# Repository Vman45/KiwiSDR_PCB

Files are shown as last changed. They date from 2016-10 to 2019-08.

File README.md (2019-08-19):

[updated 28 May 2018]

KiwiSDR (http://www.kiwisdr.com/ks/Seeed.sample.1.jpg)

Click image for full size.

[KiwiSDR© bluebison.net](http://bluebison.net)

KiwiSDR
=======

Software-defined Radio (SDR) and GPS for the BeagleBone Black
----------------------------------------------------------------------

An add-on board ("cape") that turns your Beagle into a web-accessible shortwave receiver.

This repository contains the KiCAD files (schematics, board layout), Gerbers, BOM and other files used to produce the KiwiSDR PCB.
Also included here is the design for an active antenna and bias tee.

**Note: the active antenna and bias tee schematics and PCBs here are still undergoing development and do not work properly. Do not fabricate the PCBs and expect them to work.**

The KiwiSDR software is located in the repository [Beagle_SDR_GPS](https://github.com/jks-prv/Beagle_SDR_GPS/).

### Kickstarter
KiwiSDR had a successful [Kickstarter](https://www.kickstarter.com/projects/1575992013/kiwisdr-beaglebone-software-defined-radio-sdr-with/).

### Details

* Listen live: [SDR.hu](https://sdr.hu/?top=kiwi), [kiwisdr.com](http://kiwisdr.com/public), [rx.linkfanel.net](http://rx.linkfanel.net)
* [Project webpage](http://www.kiwisdr.com/)
* [Operating information: installation, operation, FAQ](http://www.kiwisdr.com/quickstart/)
* Latest [source code commits](https://github.com/jks-prv/Beagle_SDR_GPS/commits/master)
* [Design review document](https://www.dropbox.com/s/i1bjyp1acghnc16/KiwiSDR.design.review.pdf?dl=1)
* [Schematic](http://www.kiwisdr.com/docs/KiwiSDR/kiwi.schematic.pdf), [Gerbers](http://www.kiwisdr.com/docs/KiwiSDR/kiwi.gerbers.tar), [Active antenna](http://www.kiwisdr.com/docs/KiwiSDR/ant.pdf), [BOM ODS](http://www.kiwisdr.com/docs/KiwiSDR/kiwi.bom.ods), [BOM XLS](http://www.kiwisdr.com/docs/KiwiSDR/kiwi.bom.xls)

### Description
This SDR is a bit different. It has a web interface that can be used by up to four separate listeners. Each one listening and tuning an independent frequency simultaneously. See the screenshots below.

### Components
* SDR covering the 10 kHz to 30 MHz (VLF-HF) spectrum.
* Web interface based on [OpenWebRX](http://openwebrx.org/) from András Retzler, HA7ILM.
* Integrated software-defined GPS receiver from Andrew Holme's [Homemade GPS Receiver](http://www.aholme.co.uk/GPS/Main.htm).
* LTC 14-bit 65 MHz ADC.
* Xilinx Artix-7 A35 FPGA.
* Skyworks SE4150L GPS front-end.

### Features
* 100% Open Source / Open Hardware.
* Browser-based interface allowing multiple simultaneous user web connections (currently 4).
* Each connection tunes an independent receiver channel over the entire spectrum.
* Waterfall tunes independently of audio and includes zooming and panning.
* Multi-channel, parallel DDC design using bit-width optimized CIC filters.
* Good performance at VLF/LF since we personally spend time monitoring those frequencies.
* Automatic frequency calibration via received GPS timing.
* Easy hardware and software setup. Browser-based configuration interface.

### Status

Give the live receivers a try at the links above. You'll need a recent version of a modern web browser that supports HTML5. The web interface works, with some problems, on mobile devices. But there is no mobile version of the interface yet.

The files of a KiCAD PCB layout of the cape are available. This PCB has been fabricated in production quantities
and shipped to thousands of customers worldwide.
Please email us any comments you have after reviewing the design document above. The active antenna and injector PCBs have been fabricated and are undergoing development.

### Objectives

We wanted to design an SDR that provides certain features, at a low price point, that we felt weren't covered by current devices. The SDR must be web-accessible and simple to setup and use.
We also wanted to provide a self-contained platform for experimentation with SDR and GPS techniques. 

Most importantly, We'd really like to see a significant number of web-enabled, wide-band SDRs deployed in diverse locations world-wide because that makes possible some really interesting applications and experiments.

### Operation

Users can purchase just the KiwiSDR board or a complete "kit" consisting of the board, BeagleBone Green (software pre-installed), enclosure (assembly required), and GPS antenna (see [here](http://www.kiwisdr.com/)).
The software will try to automatically open up an incoming port through whatever Internet firewall/router may exist on the local network, but the user may have to perform this step manually. An antenna solution must be provided. An adequate power supply to the Beagle (e.g. 5V @ 2A) will also be required.

Four channels of audio and waterfall streamed over the Internet 24/7 requires about 30 GB per month. This is a common cap for many residential broadband plans. An automatic dynamic-DNS system is already part of the software so a web link to the SDR is immediately available with no configuration. Of course the system can be configured to only allow connections from the local network and ignore Internet connection requests.

### Web interface screenshots

Click images for full size.

View of entire 0-30 MHz range:

(http://www.kiwisdr.com/ks/ss.full.jpg)

Moderate zoom of medium-wave broadcast band with spectrum display on top enabled:

(http://www.kiwisdr.com/ks/ss.MW.jpg)

Over-the-horizon-radar (OTHR) from Cyprus showing short-term ionospheric fluctuations:

(http://www.kiwisdr.com/ks/ss.Cyprus.jpg)

VLF/LF reception in New Zealand

| kHz | Station | Location | Signal |
| :-- | :--- | :--- | :----- |
| 12.88 | Alpha | Khabarovsk & Novosibirsk Russia | Navigation system |
| 17.0 | VTX2 | India | MSK comms |
| 19.8 | NWC | Australia | MSK comms |
| 21.4 | NPM | Hawaii | MSK comms |
| 22.2 | NDT/JJI | Japan | MSK comms |
| 24.1 | (UNID) | Korea, per David L Wilson | FSK comms |
| 40.0 | JJY | Japan | Time signal |
| 45.9 | NSY | Italy | MSK comms |
| 54.0 | NDI | Japan | MSK comms |
| 60.0 | JJY/WWVB | Japan, USA | Time signals |
| 68.5 | BPC | China | Time signal |

Many others heard during different times and conditions.

(http://www.kiwisdr.com/ks/ss.VLF.LF.jpg)

[end-of-document]

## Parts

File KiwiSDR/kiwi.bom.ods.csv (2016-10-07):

item# | quan | value | mfg | P/N | package | place | refs | SMD marking | fine pitch | polarized | generic substitution | OPL | specs | critical spec | notes
#1 | 1 | 10n | Murata | GRM155R71C103KA01D | SM0402 | DNL | C107 |  |  |  | YES |  | 10% X7R 16V |  | DO NOT LOAD; ceramic capacitor
#2 | 2 | U.FL | Hirose | U.FL-R-SMT-1 | U.FL | DNL | J4 J5 |  |  |  | YES |  |  |  | DO NOT LOAD; coaxial connector
#3 | 1 | (no value) |  |  | SM0402 | DNL | R407 |  |  |  | YES |  |  |  | DO NOT LOAD
#4 | 1 | 0R | Panasonic | ERJ-2GE0R00X | SM0402 | SMT | R408 |  |  |  | YES |  |  |  | zero-ohm jumper
#5 | 1 | 10R | Panasonic | ERJ-2RKF10R0X | SM0402 | SMT | R701 |  |  |  | YES |  | 1% 100mW 50V |  | thick film resistor
#6 | 1 | 28R7 | Panasonic | ERJ-2RKF28R7X | SM0402 | SMT | R403 |  |  |  | YES |  | 1% 100mW 50V |  | thick film resistor
#7 | 1 | 66R5 | Panasonic | ERJ-2RKF66R5X | SM0402 | SMT | R402 |  |  |  | YES |  | 1% 100mW 50V |  | thick film resistor
#8 | 4 | 100R | Panasonic | ERJ-2RKF1000X | SM0402 | SMT | R101 R102 R103 R401 |  |  |  | YES |  | 1% 100mW 50V |  | thick film resistor
#9 | 1 | 1K5 | Panasonic | ERJ-2RKF1501X | SM0402 | SMT | R104 |  |  |  | YES |  | 1% 100mW 50V |  | thick film resistor
#10 | 3 | 5K6 | Panasonic | ERJ-2RKF5601X | SM0402 | SMT | R303 R304 R305 |  |  |  | YES |  | 1% 100mW 50V |  | thick film resistor
#11 | 1 | 6K65 | Panasonic | ERJ-2RKF6651X | SM0402 | SMT | R702 |  |  |  | YES |  | 1% 100mW 50V |  | thick film resistor
#12 | 4 | 10K | Panasonic | ERJ-2RKF1002X | SM0402 | SMT | R406 R409 R410 R703 |  |  |  | YES |  | 1% 100mW 50V |  | thick film resistor
#13 | 2 | 100R | Bourns | CAY16-101J8LF | RNET_CAY16_J8 | SMT | R404 R405 |  | FINE |  | YES |  | 5% 62.5mW 25V |  | isolated resistor array
#14 | 2 | 22p | Murata | GRM1555C1H220JA01D | SM0402 | SMT | C101 C104 |  |  |  | YES |  | 5% C0G 50V |  | ceramic capacitor
#15 | 2 | 56p/100 | Murata | GRM1555C2A560JA01D | SM0402 | SMT | C401 C404 |  |  |  | YES |  | 5% C0G 100V | >= 100V | ceramic capacitor
#16 | 4 | 100p | Murata | GRM1555C1H101JA01D | SM0402 | SMT | C194 C408 C411 C416 |  |  |  | YES |  | 5% C0G 50V |  | ceramic capacitor
#17 | 2 | 160p/50 | Murata | GRM1555C1H161JA01D | SM0402 | SMT | C402 C403 |  |  |  | YES |  | 5% C0G 50V | >= 50V | ceramic capacitor
#18 | 5 | 1n | Murata | GCM155R71H102KA37D | SM0402 | SMT | C407 C409 C428 C430 C432 |  |  |  | YES |  | 10% X7R 50V |  | ceramic capacitor
#19 | 8 | 10n | Murata | GRM155R71C103KA01D | SM0402 | SMT | C105 C106 C193 C303 C305 C413 C417 C425 |  |  |  | YES |  | 10% X7R 16V |  | ceramic capacitor
#20 | 14 | 100n | Murata | GRM155R71C104KA88D | SM0402 | SMT | C190 C191 C192 C195 C301 C421 C422 C423 C424 C429 C431 C433 C702 C704 |  |  |  | YES |  | 10% X7R 16V |  | ceramic capacitor
#21 | 28 | 470n | Murata | GRM155R6YA474KE01D | SM0402 | SMT | C1 C2 C3 C6 C7 C8 C11 C12 C13 C15 C16 C23 C24 C25 C26 C30 C31 C32 C33 C36 C37 C38 C39 C42 C302 C304 C410 C414 |  |  |  | YES |  | 10% X5R 35V |  | ceramic capacitor
#22 | 7 | 1u | Murata | GRM155R61E105KA12D | SM0402 | SMT | C196 C197 C418 C419 C426 C427 C705 |  |  |  | YES |  | 10% X5R 25V |  | ceramic capacitor
#23 | 3 | 2.2u | Murata | GRM155R60J225ME15D | SM0402 | SMT | C412 C415 C420 |  |  |  | YES |  | 20% X5R 6.3V |  | ceramic capacitor
#24 | 11 | 4.7u | Murata | GRM155R60J475ME47D | SM0402 | SMT | C9 C14 C17 C18 C27 C28 C34 C35 C40 C41 C706 |  |  |  | YES |  | 20% X5R 6.3V |  | ceramic capacitor
#25 | 1 | 1n/100 | Murata | GRM219R72A102KA01J | SM0805 | SMT | C405 |  |  |  | YES |  | 10% X7R 100V | >= 100V | ceramic capacitor
#26 | 1 | 22u | Murata | GRM21BR60J226ME39L | SM0805 | SMT | C701 |  |  |  | YES |  | 20% X5R 6.3V |  | ceramic capacitor
#27 | 1 | 470n/100 | AVX | ESD61C474K4T2A-28 | SM1206 | SMT | C406 |  |  |  | YES |  | 10% X7R 100V | >= 100V | ceramic capacitor
#28 | 4 | 100u | Murata | GRM31CR60J107ME39L | SM1206 | SMT | C5 C20 C29 C703 |  |  |  | YES |  | 20% X5R 6.3V |  | ceramic capacitor
#29 | 5 | FB 600Z | TDK | MMZ1005B601C | SM0402 | SMT | L102 L103 L104 L407 L408 |  |  |  | YES |  | 25% 200mA 600Z@100M |  | ferrite chip
#30 | 1 | 39nH | TDK | MLK1005S39NJ | SM0402 | SMT | L101 |  |  |  | -- NO -- |  | 5% 200mA 2GHzSelfRes 6Q@100M | >= 2GHz self-resonance (above GPS L1) | chip inductor
#31 | 3 | 150nH | TDK | MLG1005SR15J | SM0402 | SMT | L403 L405 L406 |  |  |  | YES |  | 5% 150mA 8Q@100M |  | chip inductor
#32 | 1 | 270nH | TDK | MLG1005SR27J | SM0402 | SMT | L402 |  |  |  | YES |  | 3% 100mA 8Q@100M |  | chip inductor
#33 | 2 | 330nH | TDK | MLG1005SR33J | SM0402 | SMT | L401 L404 |  |  |  | YES |  | 3% 50mA 6Q@100M |  | chip inductor
#34 | 1 | 1uH 3.7A | Bourns | SRN4018-1R0Y | INDUCTOR_4x4 | SMT | L701 |  |  |  | YES |  | ferrite 30% 3.7A |  | inductor; use: SMPS
#35 | 1 | CMC 500uH 1A | Bourns | SRF0905A-501Y | CMC | SMT | T301 | 501Y |  |  | -- NO -- |  | ferrite 50% 1A | <= 0.15R | inductor; use: bias tee
#36 | 1 | SAW L1 | RFM | SF1186G | SAW | SMT | FL101 | 2A |  |  | YES |  | 1572.42MHz 2MHzBW |  | GPS SAW filter
#37 | 1 | SE4150L | Skyworks | SE4150L-R | QFN24 | SMT | U101 |  | FINE |  | -- NO -- |  |  |  | GPS front-end
#38 | 1 | EEPROM 32Kx8 | On Semi | CAT24C256YI-GT3 | TSSOP8 | SMT | U301 |  |  |  | YES |  | 256kb=32kx8b 100k/400k/1MHz I2C |  | EEPROM
#39 | 2 | NC7SZ125 | Fairchild | NC7SZ125P5X | SC70_5 | SMT | U403 U406 | Z25 |  |  | -- NO -- |  | 3.3V 2.6nsTpd |  | clock buffer
#40 | 1 | LMR10530Y 1.0V 3A | TI | LMR10530YSD/NOPB | WSON10 | SMT | U701 |  | FINE |  | -- NO -- |  | 5.5Vin 3A 3MHz |  | step-down voltage reg
#41 | 2 | LP5907 3.3V 250mA | TI | LP5907QMFX-3.3Q1 | SOT23_5 | SMT | U104 U404 |  |  |  | -- NO -- |  | 3.3V 250mA 0.12Vdo |  | low-noise LDO voltage reg
#42 | 1 | LP5907 1.8V 250mA | TI | LP5907QMFX-1.8Q1 | SOT23_5 | SMT | U702 |  |  |  | -- NO -- |  | 1.8V 250mA 0.12Vdo |  | low-noise LDO voltage reg
#43 | 1 | SR 5A 40V | Vishay | SSB44-E3/52T | DO214_AA | SMT | D701 | S44 |  | YES | -- NO -- |  | 40V 0.42Vf 4.0AIf | <= 0.42 Vf | Schottky rectifier; use: SMPS
#44 | 2 | TVS 3.3V | Bourns | CDSOD323-T03C | SOD323 | SMT | Z401 Z402 | 3C |  |  | YES |  | 3.3Vw 4.0Vbr 7.0Vclamp 3pF |  | bi-directional TVS
#45 | 1 | 66.6666 MHz | Conner Winfield | CWX823-066.6666M | XO | SMT | U402 |  |  |  | YES |  | 3.3V 50ppm 1psTjms | <= 1ps RMS phase jitter | XO: prototype with 66.6666 MHz since distributors stock this freq; for production special order 65.000 MHz from manufacturer
#46 | 1 | 16.368 MHz | TXC | 7Q-16.368MBG-T | TCXO | SMT | X101 |  |  |  | YES |  | 3.3V clipped sinewave tempco 0.5ppm | tempco 0.5 ppm | TCXO
#47 | 2 | RF_SHIELD 29x19 | Laird | BMI-S-209-F | * | SMT | ZR401 ZR101 |  |  |  | YES |  | 29x19mm; 7mm high |  | RF shield frame
#48 | 2 | RF_SHIELD_COVER 29x19 | Laird | BMI-S-209-C | RF_SHIELD_COVER | MANUAL | ZR102 ZR402 |  |  |  | YES |  | 29x19mm |  | RF shield cover; manual install
#49 | 1 | Artix-7 A35 | Xilinx | XC7A35T-1FTG256C | FTG256 | SMT | U1 |  |  |  | -- NO -- |  | 17x17 1.0mm BGA |  | FPGA
#50 | 1 | LTC2248 | Linear Tech | LTC2248CUH#PBF | QFN32 | SMT | U401 |  | FINE |  | -- NO -- |  | 14-bit 65MHz 240mW |  | ADC
#51 | 1 | LTC6401-20 | Linear Tech | LTC6401CUD-20#PBF | QFN16 | SMT | U405 |  | FINE |  | -- NO -- |  | +20dB 6.2dBNF 1.3GHz |  | differential ADC driver
#52 | 2 | SMA | DanYang RongHua | SMAKE-11 | SMA_OPL_EM | EDGE | J2 J3 |  |  |  | YES | OPL 320160004 | 50 Ohm; edge mount | fits 1.6mm/63mil PCB thickness | SMA connector
#53 | 2 | HEADER 13x2 | Yxcon | P125-1226A0AS116A1 | BEAGLEBONE_BLACK | T/H | ZB1 |  |  |  | YES | OPL 320020092 | 13 rows; 2 pins/row; 2.54mm/0.1in; 6mm tail length |  | 13x2 0.1 inch header connector
#54 | 1 | TB_2 | Senger | GS019-2.54-02P-1 | TB_2P_2_54MM | T/H | J1 |  |  |  | YES | OPL 320110130 | 2pos 2.54mm; fits 1.6mm/63mil thick PCB |  | terminal block side wire entry
#55 | 1 | POWER JACK 2.1MM | Shenzhen Best | DC-044-A | JACK_2_1MM_TH | T/H | J6 |  |  |  | YES | OPL 320120002 | 2.1mm w/ locating pin |  | power jack

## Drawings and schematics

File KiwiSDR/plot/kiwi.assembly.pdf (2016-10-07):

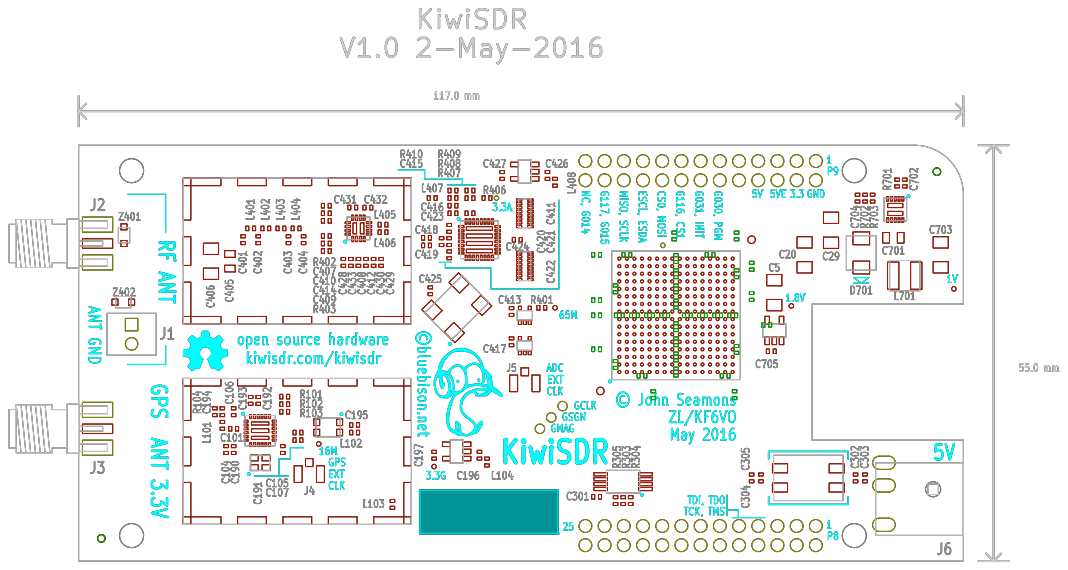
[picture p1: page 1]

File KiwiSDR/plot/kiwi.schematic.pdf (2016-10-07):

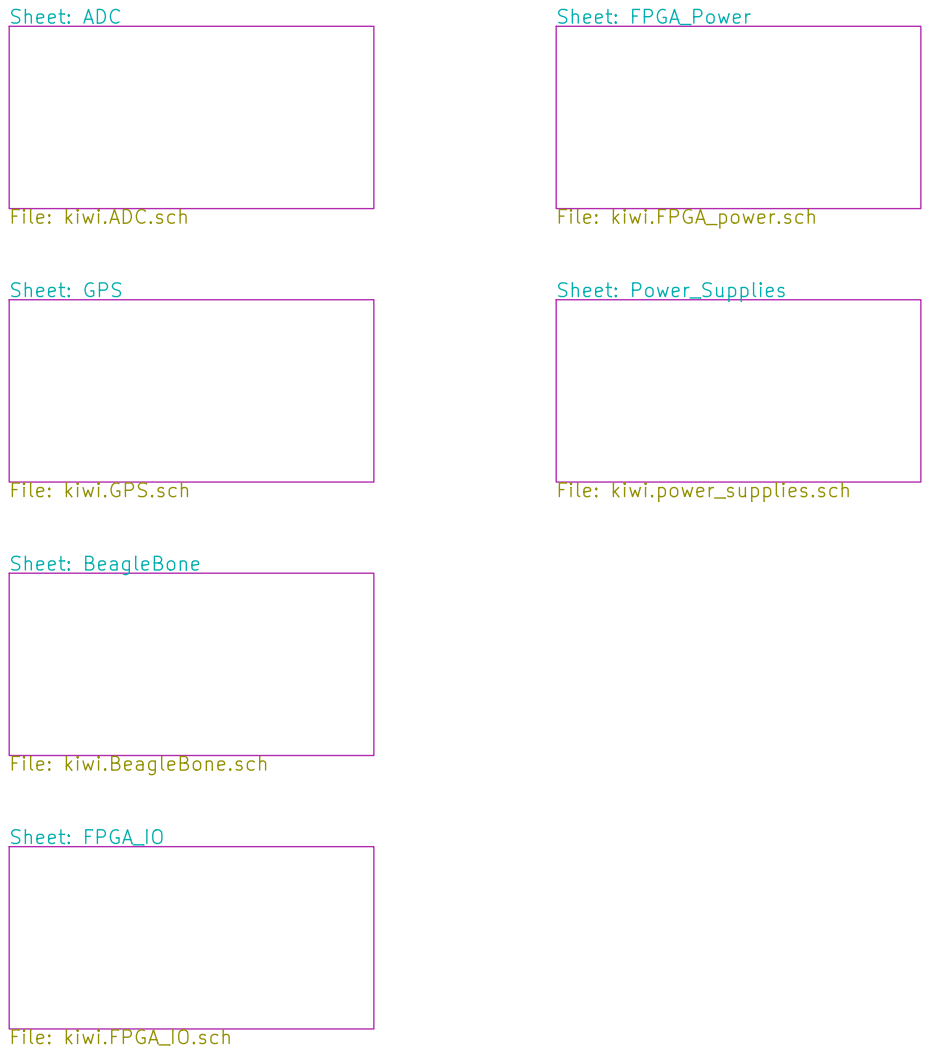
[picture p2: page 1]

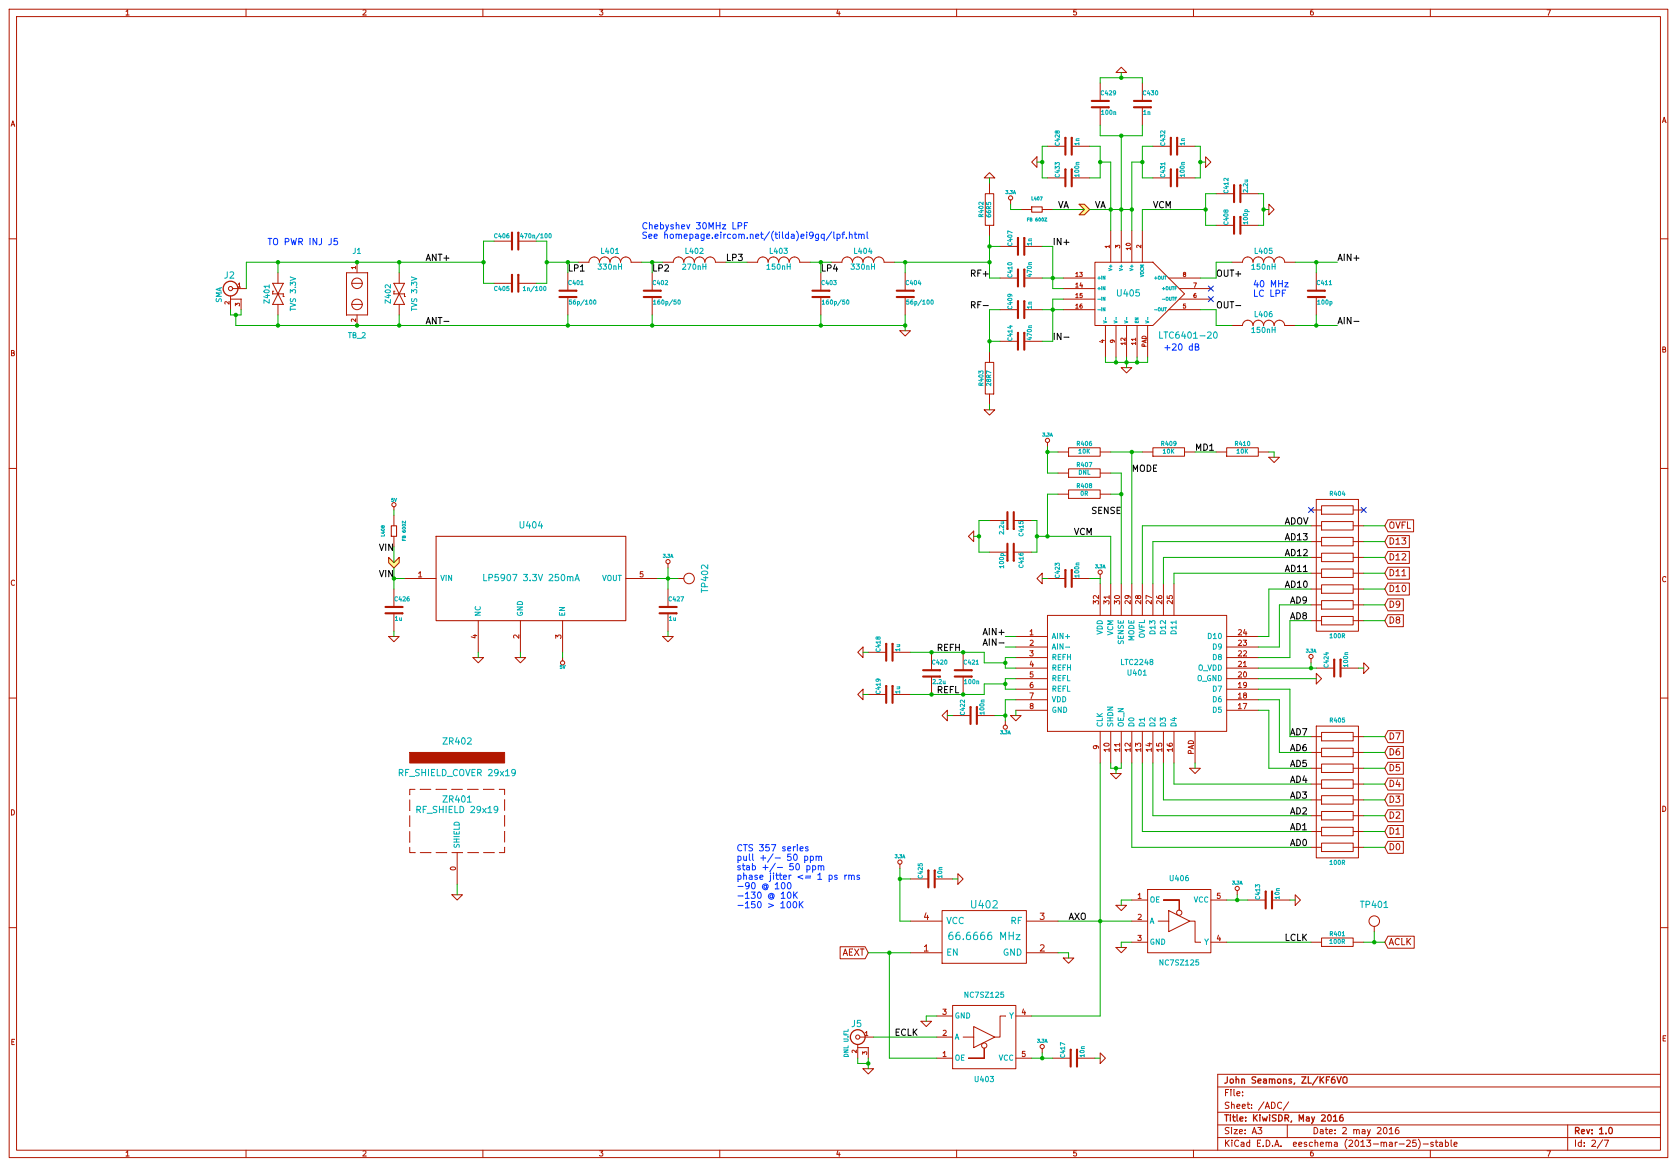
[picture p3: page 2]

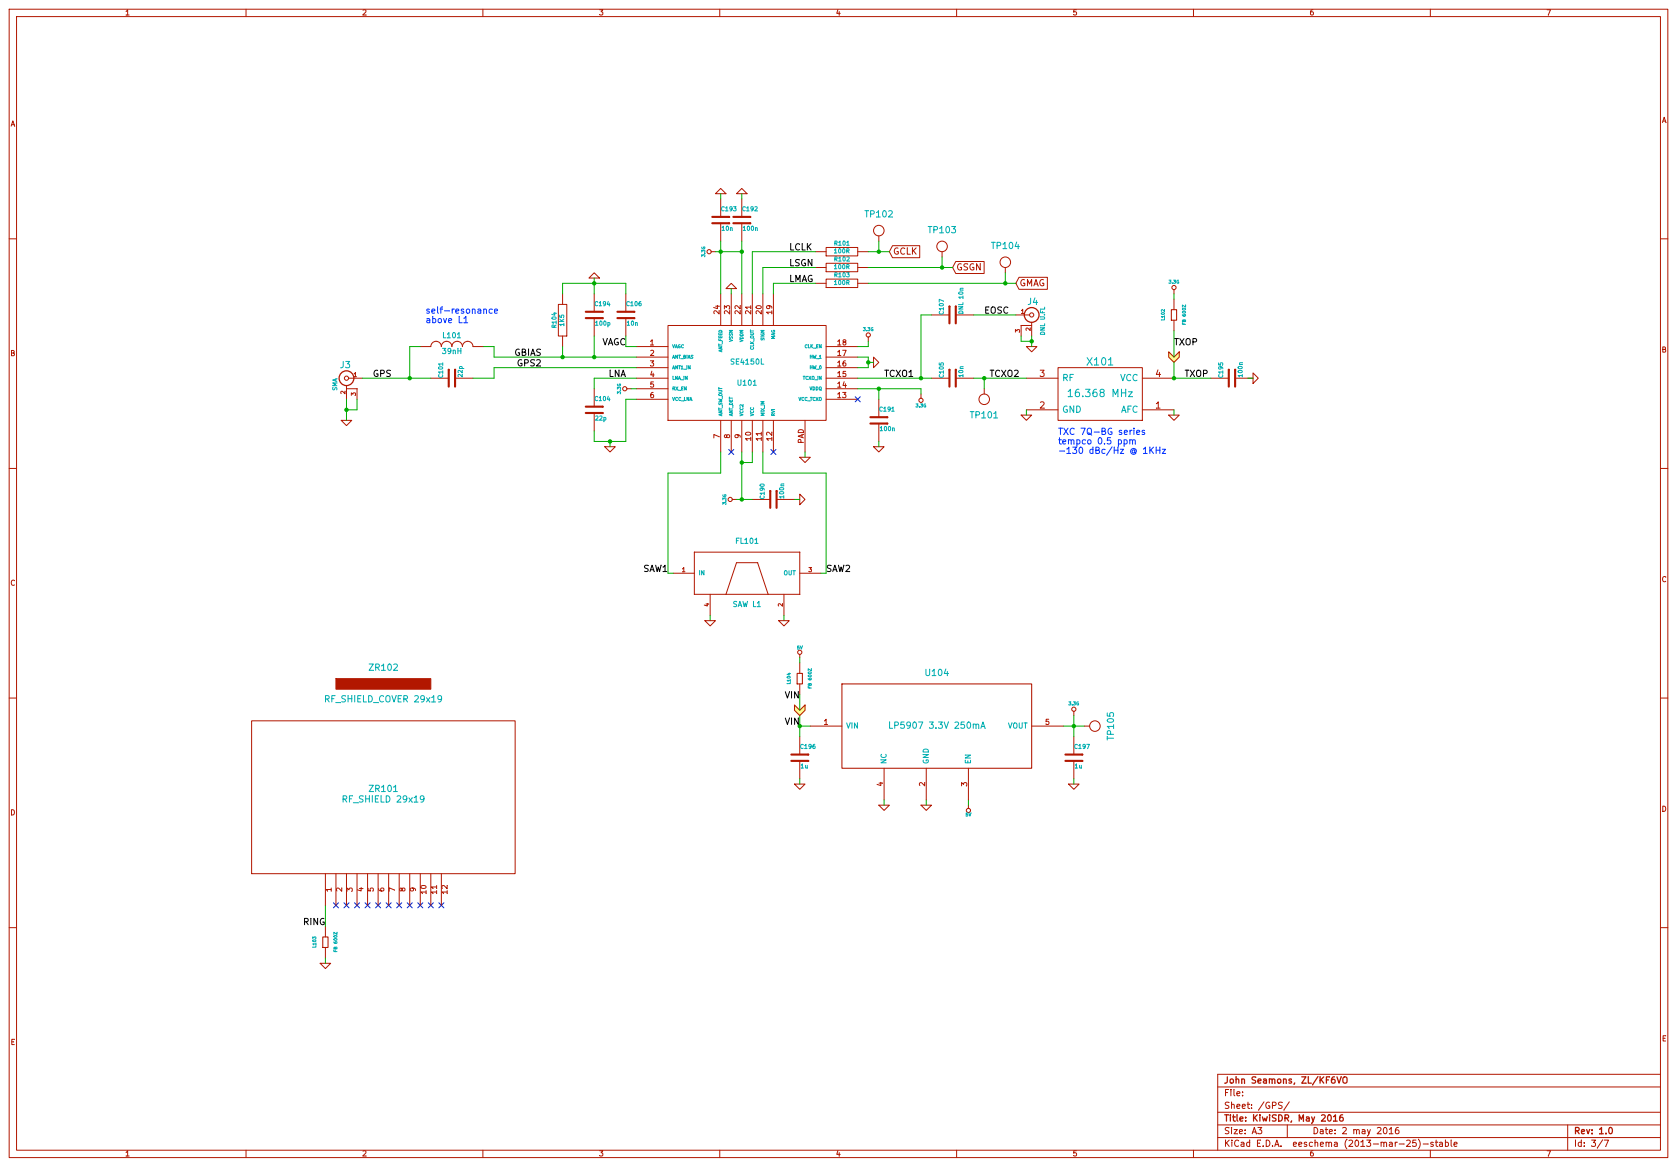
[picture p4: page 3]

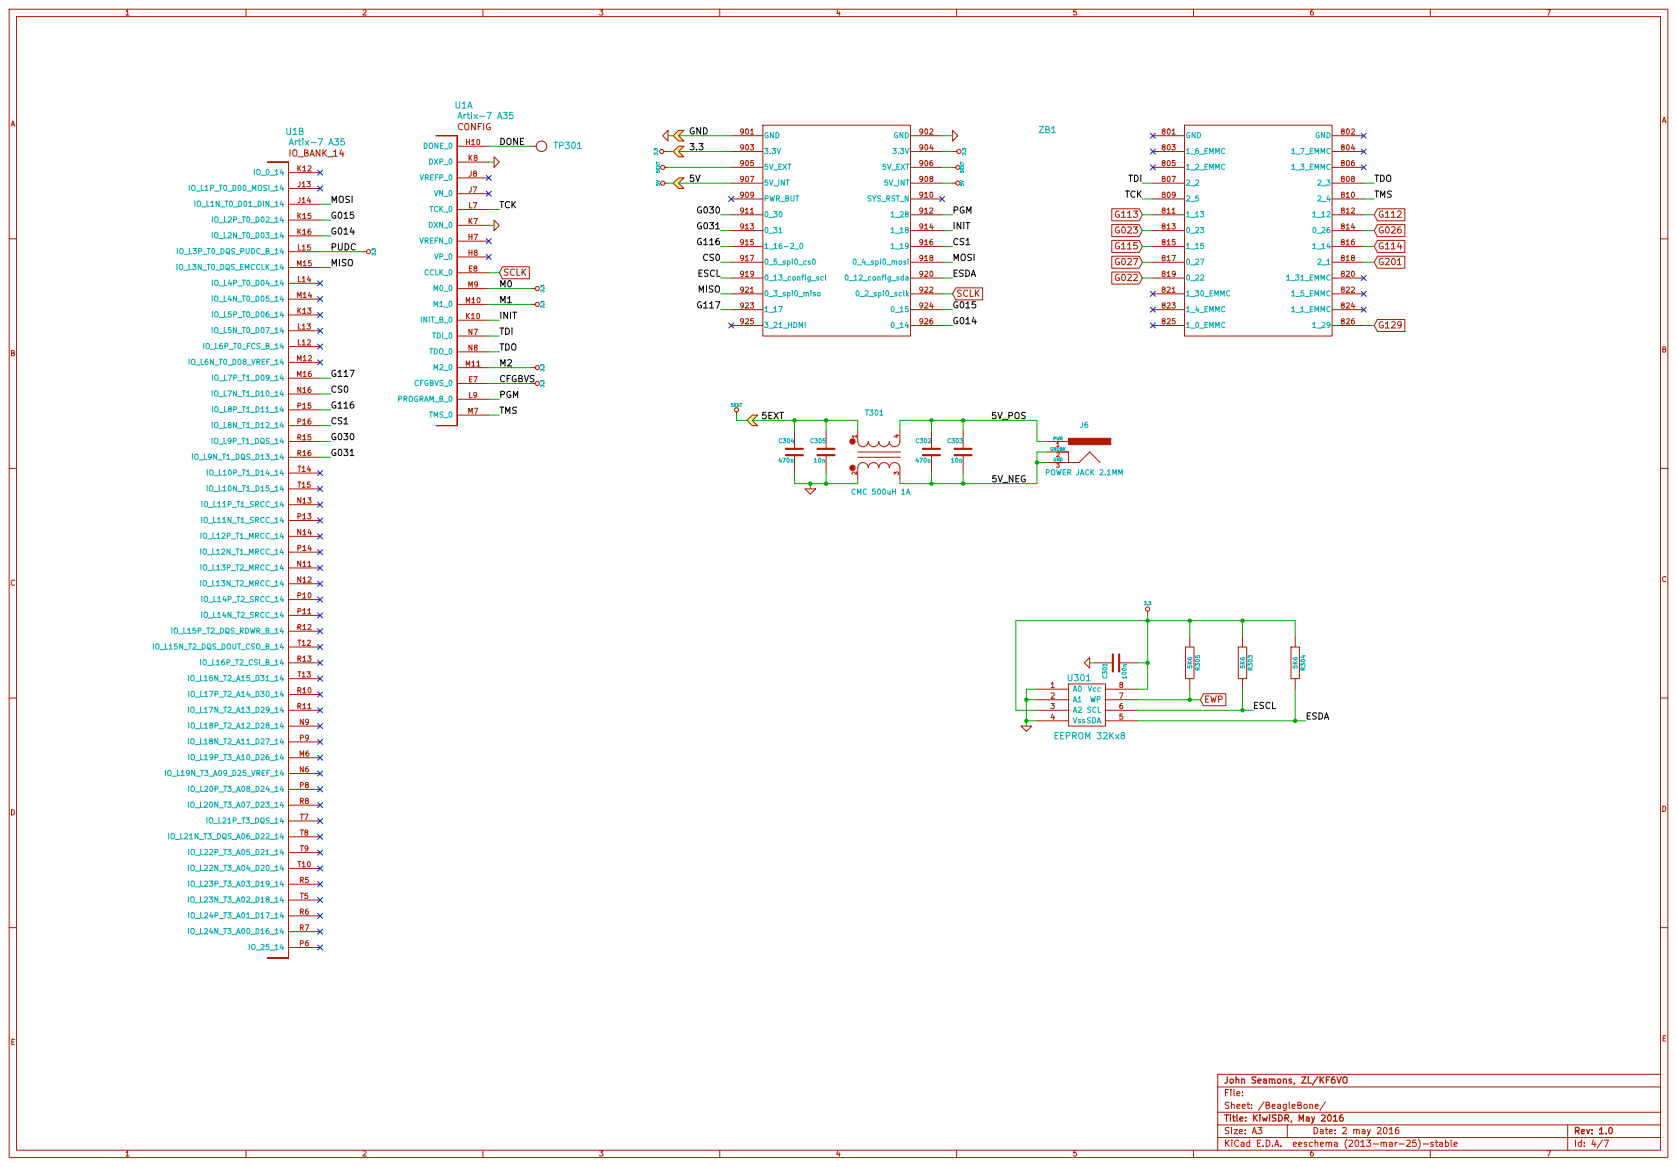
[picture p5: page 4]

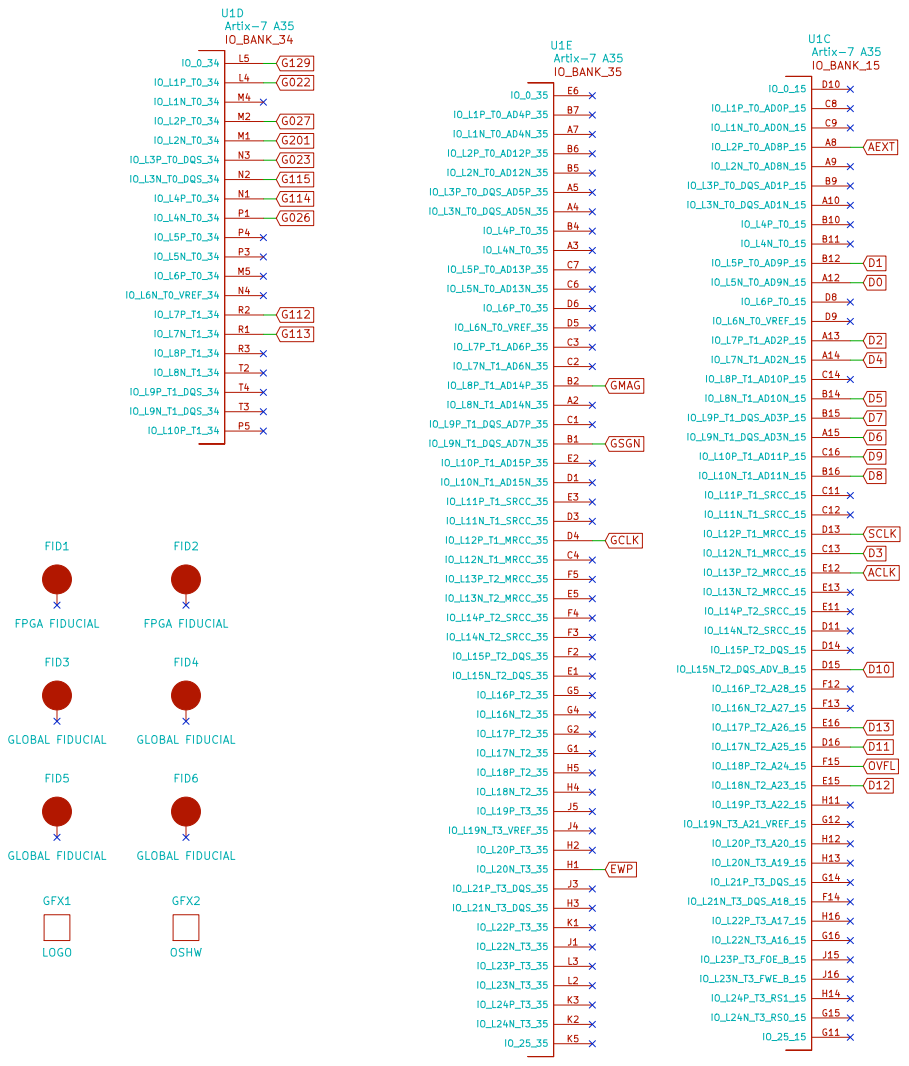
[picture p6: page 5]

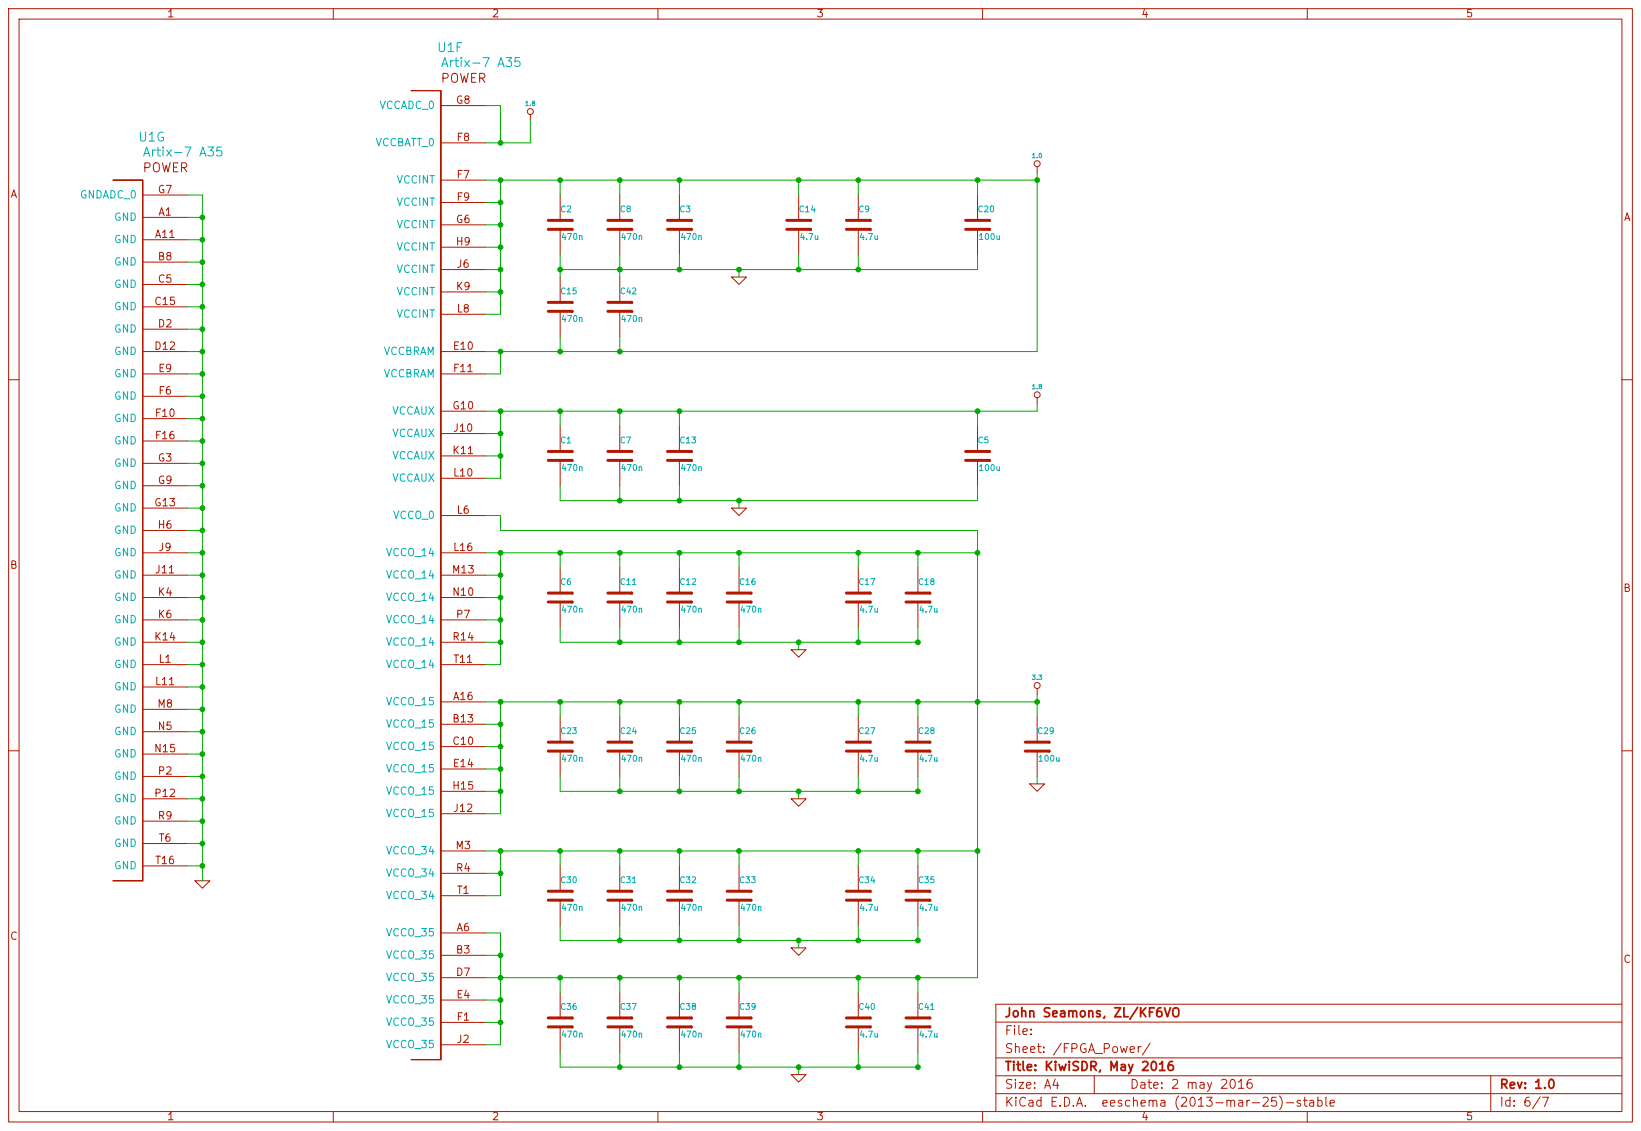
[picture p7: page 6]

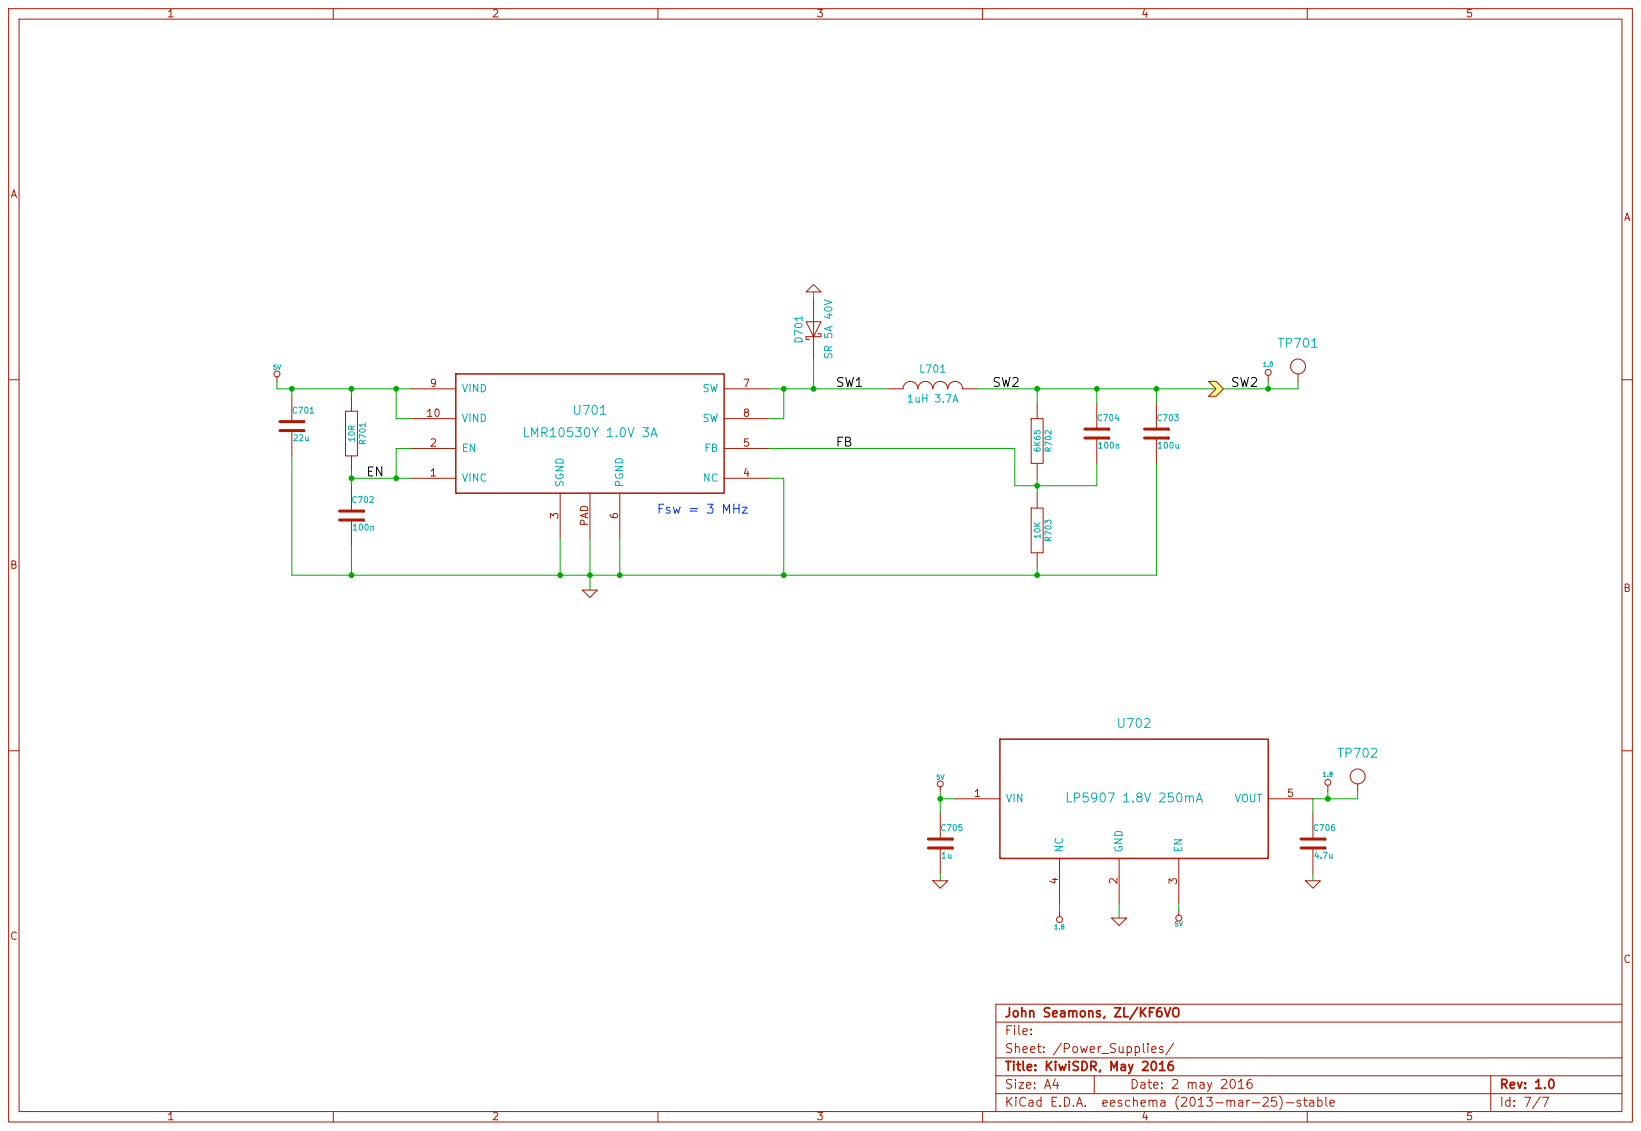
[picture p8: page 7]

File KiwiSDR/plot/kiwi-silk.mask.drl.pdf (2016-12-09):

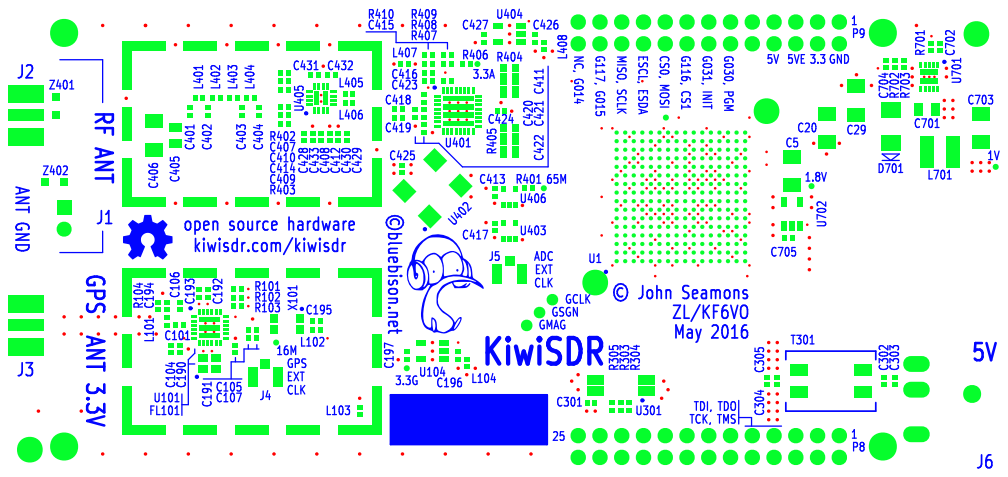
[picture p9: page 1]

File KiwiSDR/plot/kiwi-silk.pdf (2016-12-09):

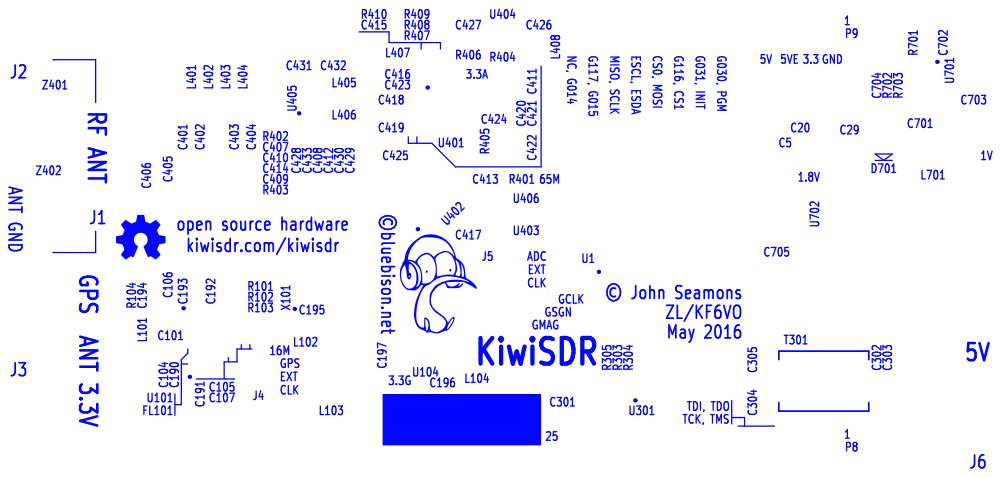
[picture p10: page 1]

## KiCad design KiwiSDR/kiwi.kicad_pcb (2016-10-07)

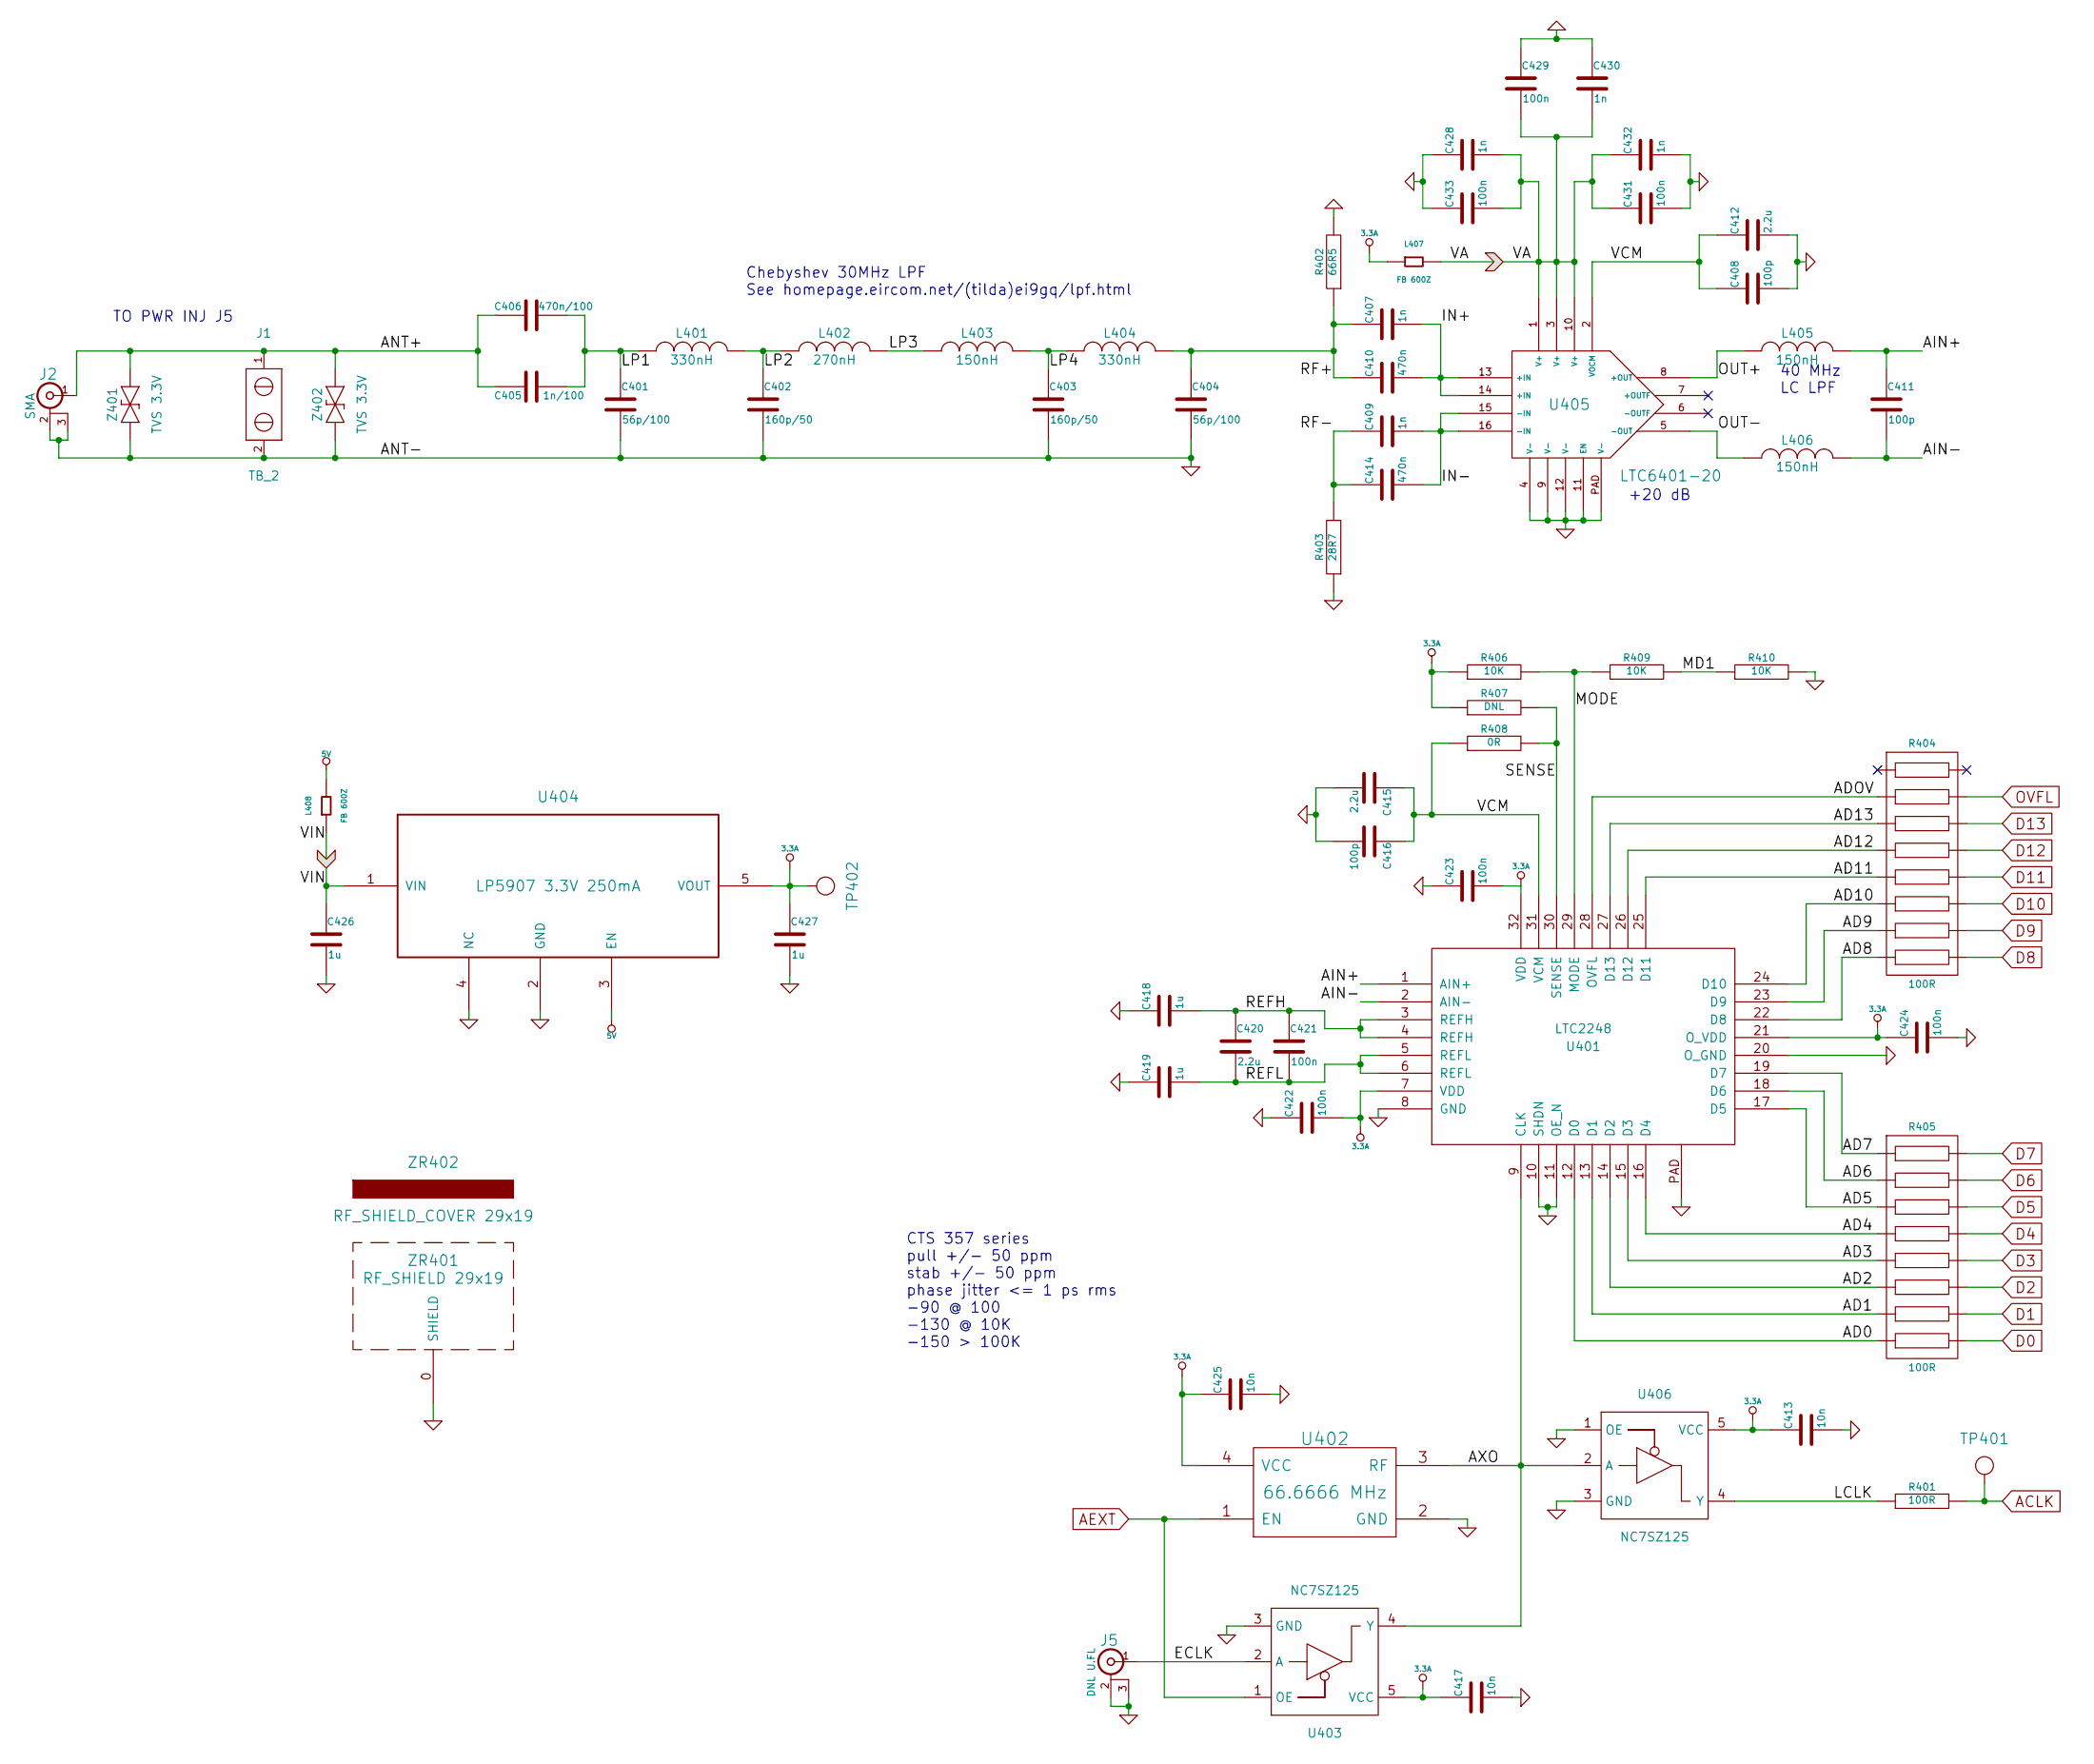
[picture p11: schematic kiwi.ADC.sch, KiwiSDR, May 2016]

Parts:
C401, C404: 56p/100; kiwi-SM0402
C402, C403: 160p/50; kiwi-SM0402
C405: 1n/100; kiwi-SM0805
C406: 470n/100; kiwi-SM1206
C407, C409, C428, C430, C432: 1n; kiwi-SM0402
C408, C411, C416: 100p; kiwi-SM0402
C410, C414: 470n; kiwi-SM0402
C412, C415, C420: 2.2u; kiwi-SM0402
C413, C417, C425: 10n; kiwi-SM0402
C418, C419, C426, C427: 1u; kiwi-SM0402
C421, C422, C423, C424, C429, C431, C433: 100n; kiwi-SM0402
J1: TB_2; kiwi-TB_2P_2_54MM
J2: SMA; kiwi-SMA_OPL_EM
J5: DNL U.FL; kiwi-U.FL
L401, L404: 330nH; kiwi-SM0402
L402: 270nH; kiwi-SM0402
L403, L405, L406: 150nH; kiwi-SM0402
L407, L408: FB 600Z; kiwi-SM0402
R401: 100R; kiwi-SM0402
R402: 66R5; kiwi-SM0402
R403: 28R7; kiwi-SM0402
R404, R405: 100R; kiwi-RNET_CAY16_J8
R406, R409, R410: 10K; kiwi-SM0402
R407: DNL; kiwi-SM0402
R408: 0R; kiwi-SM0402
TP401: TEST_POINT; kiwi-TP_600
TP402: TEST_POINT; kiwi-TP_VIA_600
U401: LTC2248; kiwi-QFN32
U402: 66.6666 MHz; kiwi-XO
U403, U406: NC7SZ125; kiwi-SC70_5
U404: LP5907 3.3V 250mA; kiwi-SOT23_5
U405: LTC6401-20; kiwi-QFN16
Z401, Z402: TVS 3.3V; kiwi-SOD323
ZR401: RF_SHIELD 29x19; kiwi-RF_SHIELD_29x19
ZR402: RF_SHIELD_COVER 29x19; kiwi-RF_SHIELD_COVER

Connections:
3.3A: C413.1, C417.1, C422.2, C423.2, C424.1, C425.1, C427.1, L407.1, R406.1, R407.1, TP402.1, U401.7 (VDD), U401.21 (O_VDD), U401.32 (VDD), U402.4 (VCC), U403.5 (VCC), U404.5 (VOUT), U406.5 (VCC)
/ADC/AD0: R405.15, U401.12 (D0)
/ADC/AD1: R405.13, U401.13 (D1)
/ADC/AD2: R405.11, U401.14 (D2)
/ADC/AD3: R405.9, U401.15 (D3)
/ADC/AD4: R405.7, U401.16 (D4)
/ADC/AD5: R405.5, U401.17 (D5)
/ADC/AD6: R405.3, U401.18 (D6)
/ADC/AD7: R405.1, U401.19 (D7)
/ADC/AD8: R404.15, U401.22 (D8)
/ADC/AD9: R404.13, U401.23 (D9)
/ADC/AD10: R404.11, U401.24 (D10)
/ADC/AD11: R404.9, U401.25 (D11)
/ADC/AD12: R404.7, U401.26 (D12)
/ADC/AD13: R404.5, U401.27 (D13)
/ADC/ADOV: R404.3, U401.28 (OVFL)
/ADC/AIN+: C411.1, L405.2, U401.1 (AIN+)
/ADC/AIN-: C411.2, L406.2, U401.2 (AIN-)
/ADC/ANT+: C405.1, C406.1, J1.1, J2.1 (In), Z401.2, Z402.2
/ADC/AXO: U401.9 (CLK), U402.3 (RF), U403.4 (Y), U406.2 (A)
/ADC/ECLK: J5.1 (In), U403.2 (A)
/ADC/IN+: C407.2, C410.2, U405.13 (+IN), U405.14 (+IN)
/ADC/IN-: C409.2, C414.2, U405.15 (-IN), U405.16 (-IN)
/ADC/LCLK: R401.1, U406.4 (Y)
/ADC/LP1: C401.1, C405.2, C406.2, L401.1
/ADC/LP2: C402.1, L401.2, L402.1
/ADC/LP3: L402.2, L403.1
/ADC/LP4: C403.1, L403.2, L404.1
/ADC/MD1: R409.2, R410.1
/ADC/MODE: R406.2, R409.1, U401.29 (MODE)
/ADC/OUT+: L405.1, U405.8 (+OUT)
/ADC/OUT-: L406.1, U405.5 (-OUT)
/ADC/REFH: C418.2, C420.1, C421.1, U401.3 (REFH), U401.4 (REFH)
/ADC/REFL: C419.2, C420.2, C421.2, U401.5 (REFL), U401.6 (REFL)
/ADC/RF+: C404.1, C407.1, C410.1, L404.2, R402.1
/ADC/RF-: C409.1, C414.1, R403.2
/ADC/SENSE: R407.2, R408.2, U401.30 (SENSE)
/ADC/VCM: C408.1, C412.1, C415.1, C416.1, R408.1, U401.31 (VCM), U405.2 (VOCM)
ACLK: R401.2, TP401.1; also elsewhere on the board
AEXT: U402.1 (EN), U403.1 (OE); also elsewhere on the board
D0: R405.16; also elsewhere on the board
D1: R405.14; also elsewhere on the board
D2: R405.12; also elsewhere on the board
D3: R405.10; also elsewhere on the board
D4: R405.8; also elsewhere on the board
D5: R405.6; also elsewhere on the board
D6: R405.4; also elsewhere on the board
D7: R405.2; also elsewhere on the board
D8: R404.16; also elsewhere on the board
D9: R404.14; also elsewhere on the board
D10: R404.12; also elsewhere on the board
D11: R404.10; also elsewhere on the board
D12: R404.8; also elsewhere on the board
D13: R404.6; also elsewhere on the board
OVFL: R404.4; also elsewhere on the board

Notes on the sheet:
CTS 357 series pull +/- 50 ppm stab +/- 50 ppm phase jitter <= 1 ps rms -90 @ 100 -130 @ 10K -150 > 100K
Chebyshev 30MHz LPF See homepage.eircom.net/(tilda)ei9gq/lpf.html
40 MHz LC LPF
+20 dB
TO PWR INJ J5

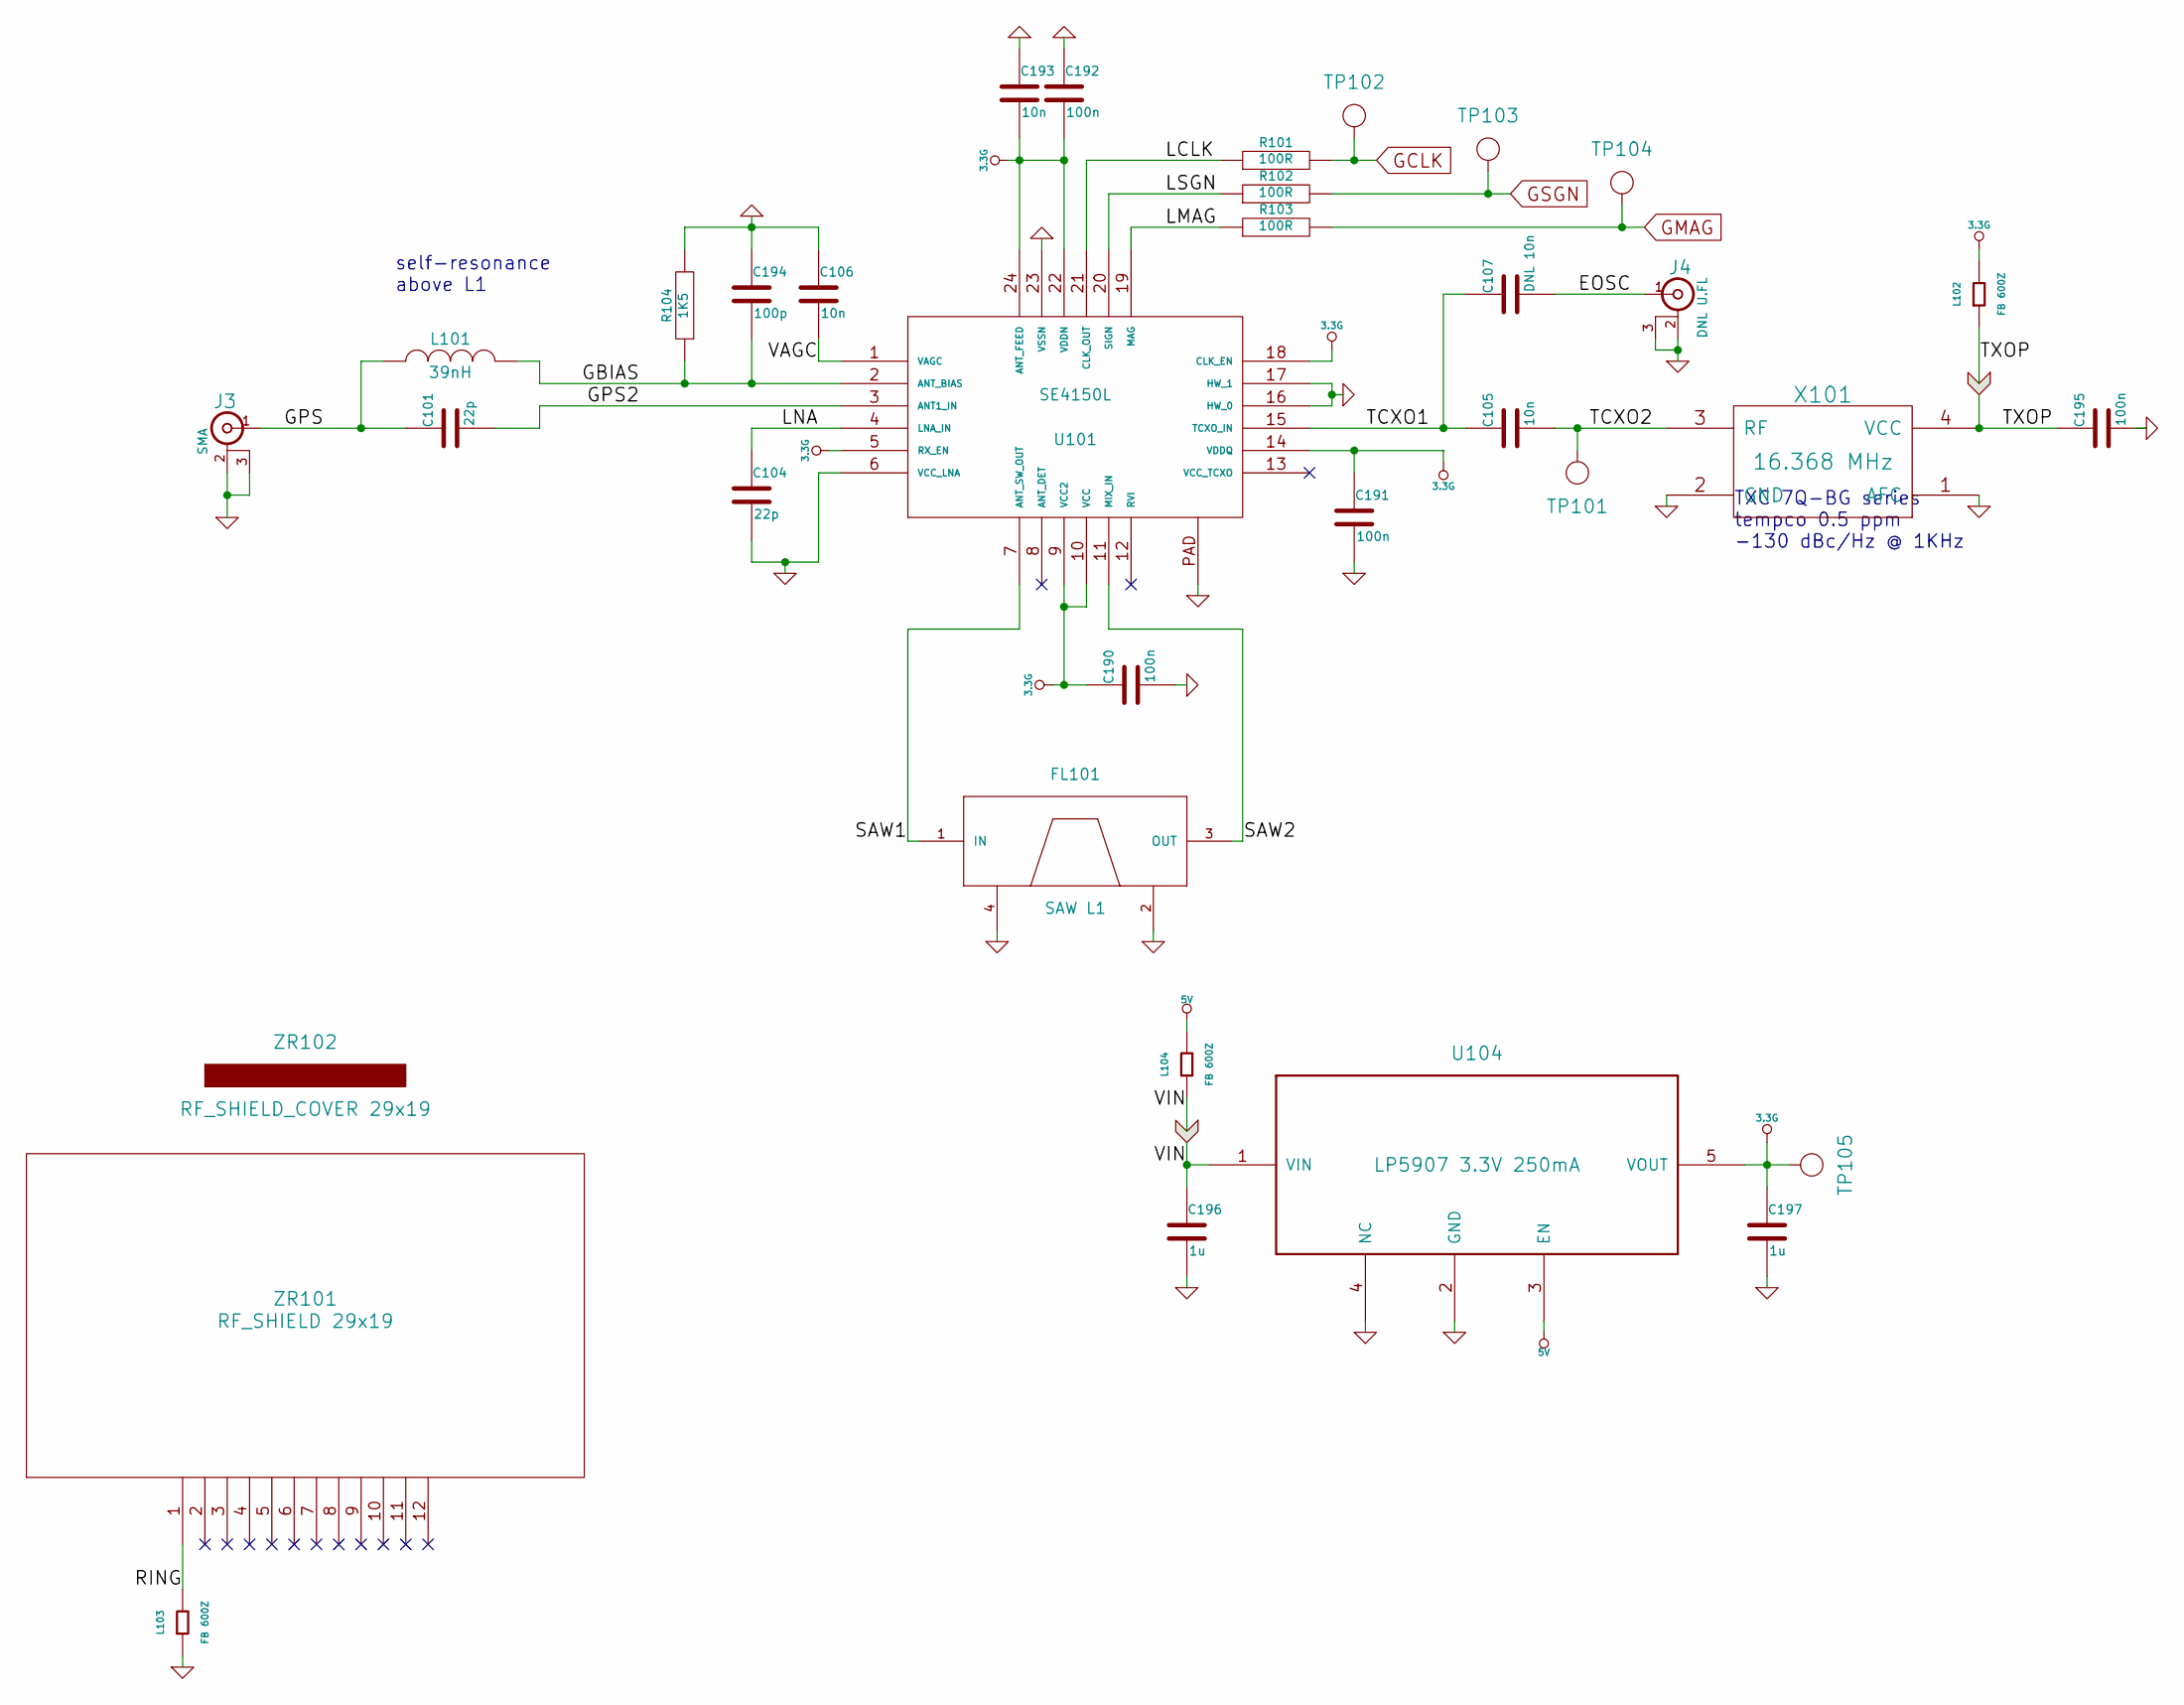
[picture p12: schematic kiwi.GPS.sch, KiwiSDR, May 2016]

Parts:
C101, C104: 22p; kiwi-SM0402
C105, C106, C193: 10n; kiwi-SM0402
C107: DNL 10n; kiwi-SM0402
C190, C191, C192, C195: 100n; kiwi-SM0402
C194: 100p; kiwi-SM0402
C196, C197: 1u; kiwi-SM0402
FL101: SAW L1; kiwi-SAW
J3: SMA; kiwi-SMA_OPL_EM
J4: DNL U.FL; kiwi-U.FL
L101: 39nH; kiwi-SM0402
L102, L103, L104: FB 600Z; kiwi-SM0402
R101, R102, R103: 100R; kiwi-SM0402
R104: 1K5; kiwi-SM0402
TP101, TP105: TEST_POINT; kiwi-TP_600
TP102, TP103, TP104: TEST_POINT; kiwi-TP_VIA_1250
U101: SE4150L; kiwi-QFN24
U104: LP5907 3.3V 250mA; kiwi-SOT23_5
X101: 16.368 MHz; kiwi-TCXO
ZR101: RF_SHIELD 29x19; kiwi-RF_SHIELD_29x19_16P
ZR102: RF_SHIELD_COVER 29x19; kiwi-RF_SHIELD_COVER

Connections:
3.3G: C190.1, C191.1, C192.2, C193.2, C197.1, L102.2, TP105.1, U101.5 (RX_EN), U101.9 (VCC2), U101.10 (VCC), U101.14 (VDDQ), U101.18 (CLK_EN), U101.22 (VDDN), U101.24 (ANT_FEED), U104.5 (VOUT)
/GPS/EOSC: C107.2, J4.1 (In)
/GPS/GBIAS: C194.2, L101.2, R104.1, U101.2 (ANT_BIAS)
/GPS/GPS: C101.1, J3.1 (In), L101.1
/GPS/GPS2: C101.2, U101.3 (ANT1_IN)
/GPS/LCLK: R101.1, U101.21 (CLK_OUT)
/GPS/LMAG: R103.1, U101.19 (MAG)
/GPS/LNA: C104.1, U101.4 (LNA_IN)
/GPS/LSGN: R102.1, U101.20 (SIGN)
/GPS/RING: L103.2, ZR101.1
/GPS/SAW1: FL101.1 (IN), U101.7 (ANT_SW_OUT)
/GPS/SAW2: FL101.3 (OUT), U101.11 (MIX_IN)
/GPS/TCXO1: C105.1, C107.1, U101.15 (TCXO_IN)
/GPS/TCXO2: C105.2, TP101.1, X101.3 (RF)
/GPS/VAGC: C106.2, U101.1 (VAGC)
GCLK: R101.2, TP102.1; also elsewhere on the board
GMAG: R103.2, TP104.1; also elsewhere on the board
GSGN: R102.2, TP103.1; also elsewhere on the board

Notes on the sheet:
self-resonance above L1
TXC 7Q-BG series tempco 0.5 ppm -130 dBc/Hz @ 1KHz

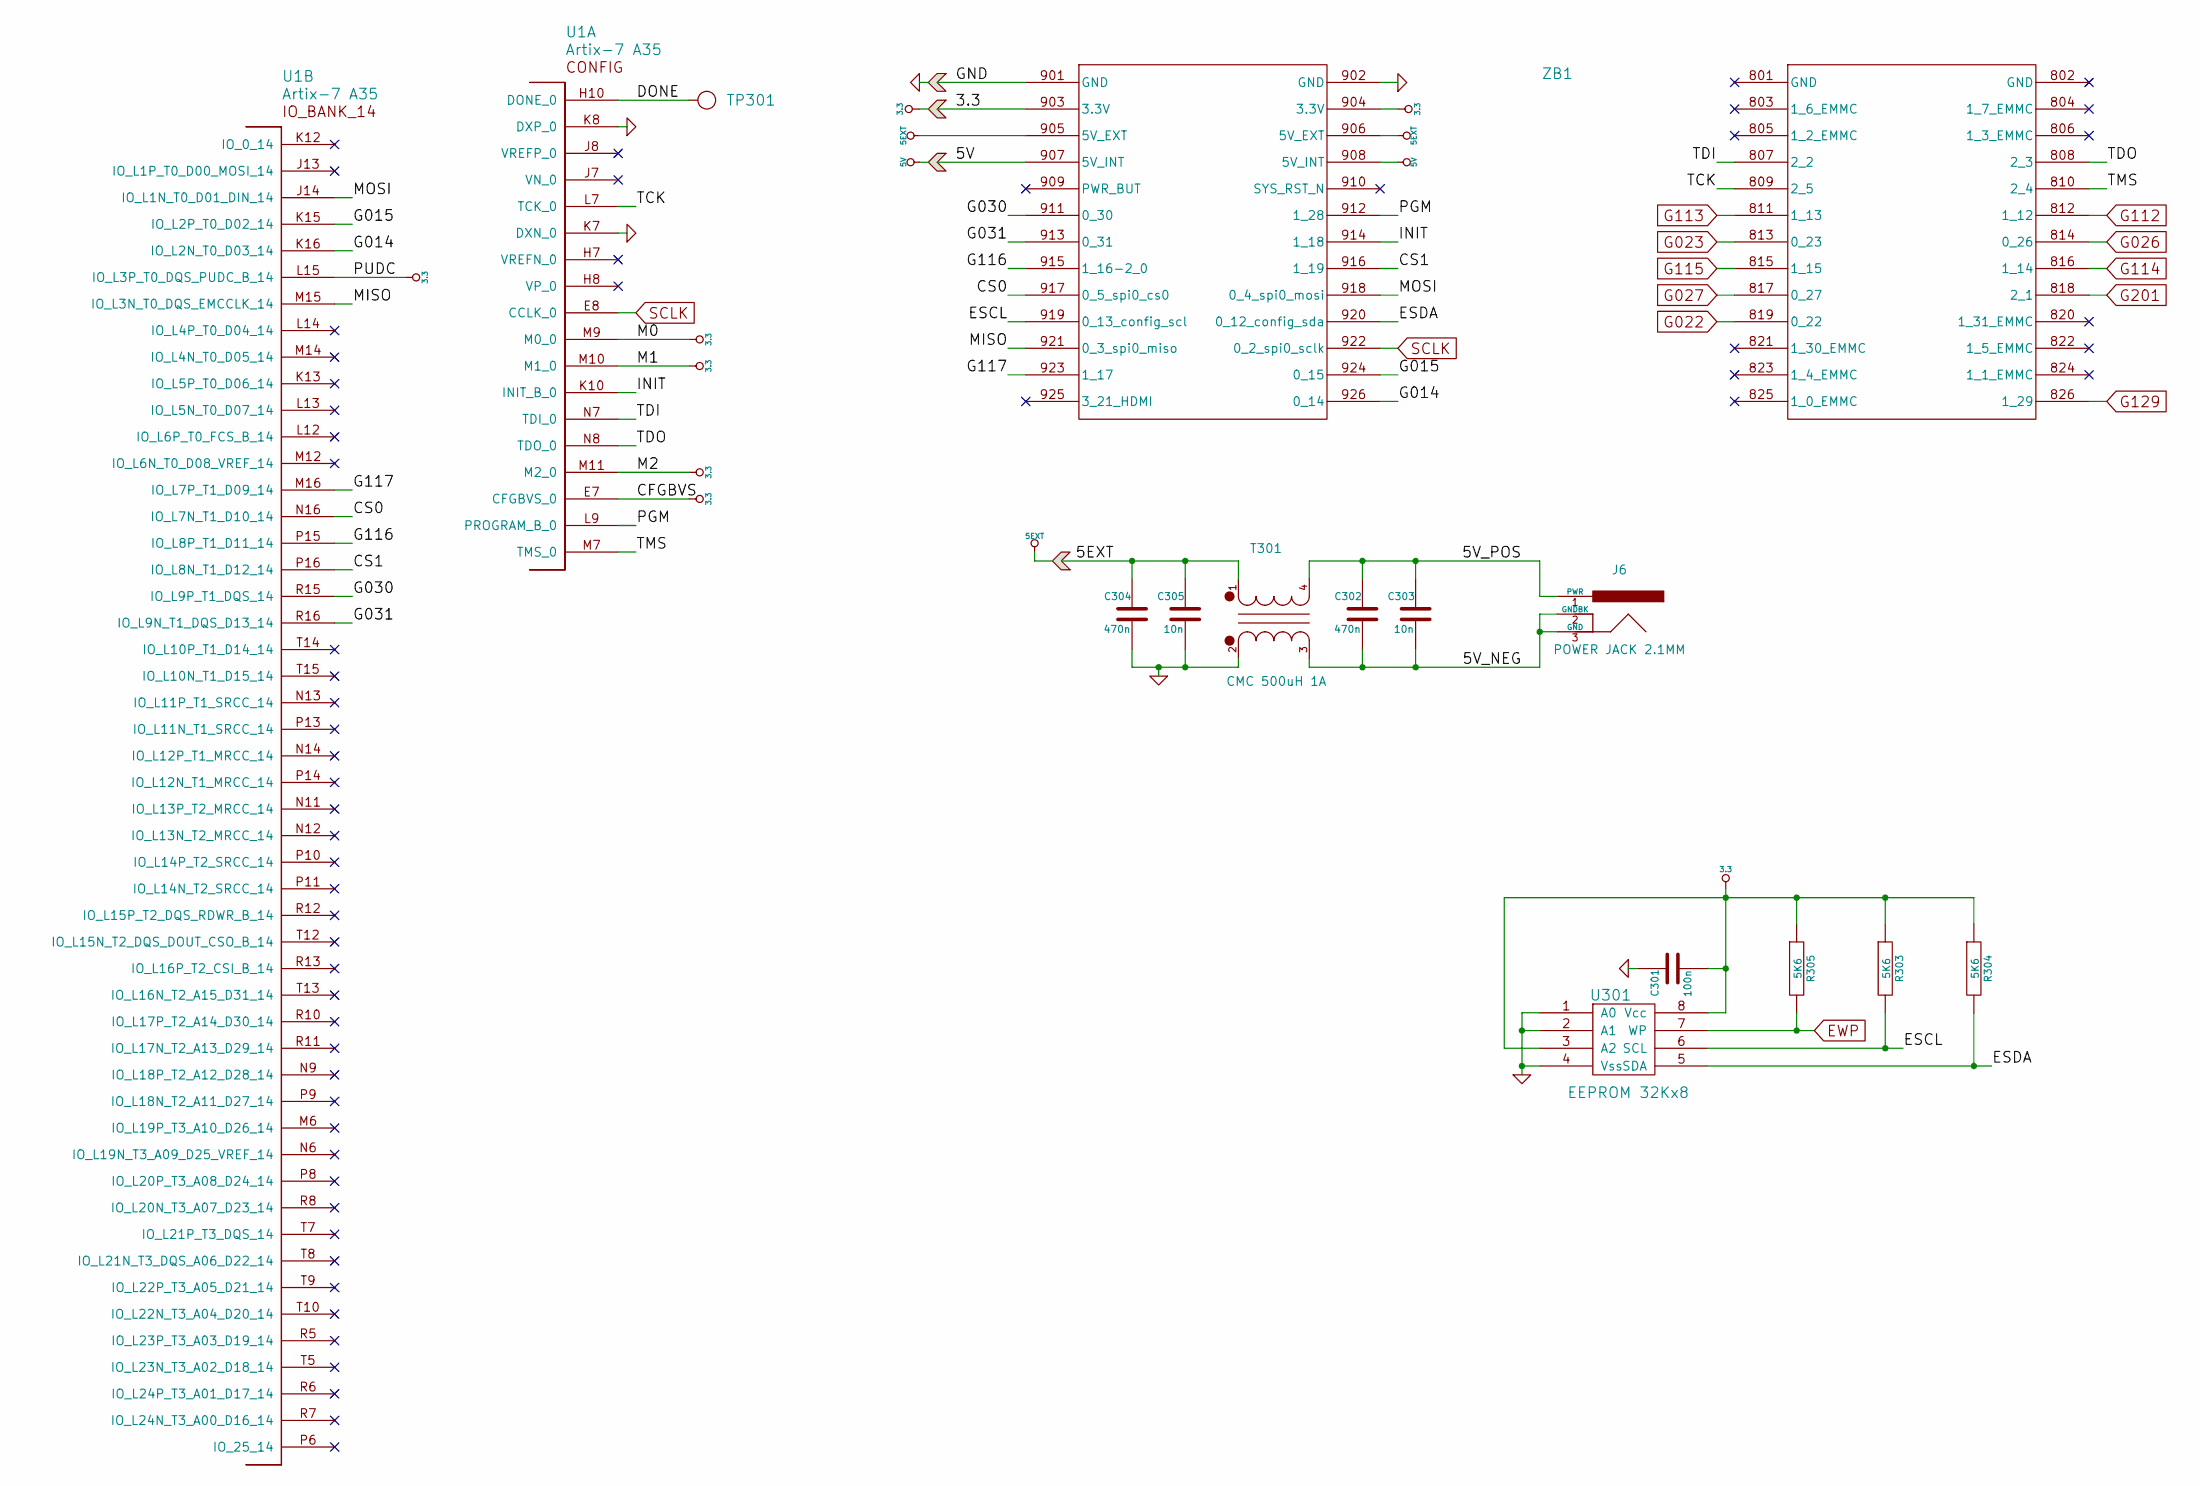
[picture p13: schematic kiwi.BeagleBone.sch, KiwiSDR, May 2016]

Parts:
C301: 100n; kiwi-SM0402
C302, C304: 470n; kiwi-SM0402
C303, C305: 10n; kiwi-SM0402
J6: POWER JACK 2.1MM; kiwi-JACK_2_1MM_TH
R303, R304, R305: 5K6; kiwi-SM0402
T301: CMC 500uH 1A; kiwi-CMC
TP301: TEST_POINT; kiwi-TP_VIA_600
U1: Artix-7 A35; kiwi-FTG256
U301: EEPROM 32Kx8; kiwi-TSSOP8
ZB1: HEADER 13x2; kiwi-BEAGLEBONE_BLACK

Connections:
/BeagleBone/5V_NEG: C302.2, C303.2, J6.2 (GNDBK), J6.3 (GND), T301.3
/BeagleBone/5V_POS: C302.1, C303.1, J6.1 (PWR), T301.4
/BeagleBone/CS0: U1.N16 (IO_L7N_T1_D10_14), ZB1.917 (0_5_spi0_cs0)
/BeagleBone/CS1: U1.P16 (IO_L8N_T1_D12_14), ZB1.916 (1_19)
/BeagleBone/DONE: TP301.1, U1.H10 (DONE_0)
/BeagleBone/ESCL: R303.2, U301.6 (SCL), ZB1.919 (0_13_config_scl)
/BeagleBone/ESDA: R304.2, U301.5 (SDA), ZB1.920 (0_12_config_sda)
/BeagleBone/G014: U1.K16 (IO_L2N_T0_D03_14), ZB1.926 (0_14)
/BeagleBone/G015: U1.K15 (IO_L2P_T0_D02_14), ZB1.924 (0_15)
/BeagleBone/G030: U1.R15 (IO_L9P_T1_DQS_14), ZB1.911 (0_30)
/BeagleBone/G031: U1.R16 (IO_L9N_T1_DQS_D13_14), ZB1.913 (0_31)
/BeagleBone/G116: U1.P15 (IO_L8P_T1_D11_14), ZB1.915 (1_16-2_0)
/BeagleBone/G117: U1.M16 (IO_L7P_T1_D09_14), ZB1.923 (1_17)
/BeagleBone/INIT: U1.K10 (INIT_B_0), ZB1.914 (1_18)
/BeagleBone/MISO: U1.M15 (IO_L3N_T0_DQS_EMCCLK_14), ZB1.921 (0_3_spi0_miso)
/BeagleBone/MOSI: U1.J14 (IO_L1N_T0_D01_DIN_14), ZB1.918 (0_4_spi0_mosi)
/BeagleBone/PGM: U1.L9 (PROGRAM_B_0), ZB1.912 (1_28)
/BeagleBone/TCK: U1.L7 (TCK_0), ZB1.809 (2_5)
/BeagleBone/TDI: U1.N7 (TDI_0), ZB1.807 (2_2)
/BeagleBone/TDO: U1.N8 (TDO_0), ZB1.808 (2_3)
/BeagleBone/TMS: U1.M7 (TMS_0), ZB1.810 (2_4)
EWP: R305.2, U301.7 (WP); also elsewhere on the board
G022: ZB1.819 (0_22); also elsewhere on the board
G023: ZB1.813 (0_23); also elsewhere on the board
G026: ZB1.814 (0_26); also elsewhere on the board
G027: ZB1.817 (0_27); also elsewhere on the board
G112: ZB1.812 (1_12); also elsewhere on the board
G113: ZB1.811 (1_13); also elsewhere on the board
G114: ZB1.816 (1_14); also elsewhere on the board
G115: ZB1.815 (1_15); also elsewhere on the board
G129: ZB1.826 (1_29); also elsewhere on the board
G201: ZB1.818 (2_1); also elsewhere on the board
SCLK: U1.E8 (CCLK_0), ZB1.922 (0_2_spi0_sclk); also elsewhere on the board

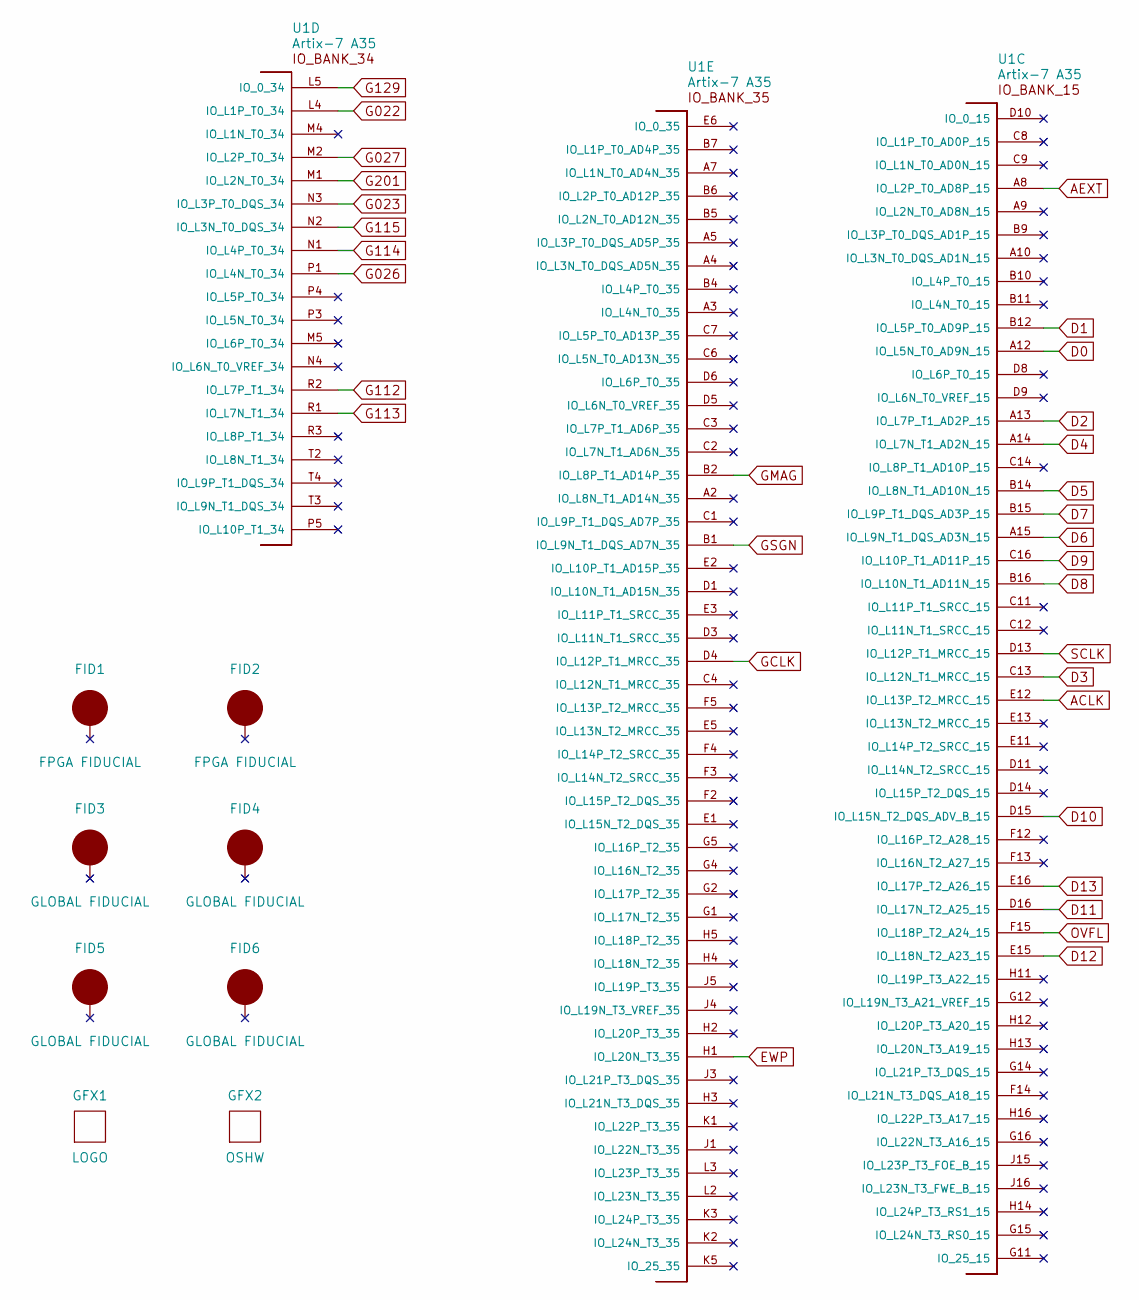
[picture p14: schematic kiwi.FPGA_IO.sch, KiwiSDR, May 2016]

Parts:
FID1, FID2: FPGA FIDUCIAL; kiwi-FIDUCIAL
FID3, FID4, FID5, FID6: GLOBAL FIDUCIAL; kiwi-FIDUCIAL
GFX1: LOGO; kiwi-KIWI_10MM
GFX2: OSHW; kiwi-OSHW_6MM
U1: Artix-7 A35; kiwi-FTG256

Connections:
ACLK: U1.E12 (IO_L13P_T2_MRCC_15); also elsewhere on the board
AEXT: U1.A8 (IO_L2P_T0_AD8P_15); also elsewhere on the board
D0: U1.A12 (IO_L5N_T0_AD9N_15); also elsewhere on the board
D1: U1.B12 (IO_L5P_T0_AD9P_15); also elsewhere on the board
D2: U1.A13 (IO_L7P_T1_AD2P_15); also elsewhere on the board
D3: U1.C13 (IO_L12N_T1_MRCC_15); also elsewhere on the board
D4: U1.A14 (IO_L7N_T1_AD2N_15); also elsewhere on the board
D5: U1.B14 (IO_L8N_T1_AD10N_15); also elsewhere on the board
D6: U1.A15 (IO_L9N_T1_DQS_AD3N_15); also elsewhere on the board
D7: U1.B15 (IO_L9P_T1_DQS_AD3P_15); also elsewhere on the board
D8: U1.B16 (IO_L10N_T1_AD11N_15); also elsewhere on the board
D9: U1.C16 (IO_L10P_T1_AD11P_15); also elsewhere on the board
D10: U1.D15 (IO_L15N_T2_DQS_ADV_B_15); also elsewhere on the board
D11: U1.D16 (IO_L17N_T2_A25_15); also elsewhere on the board
D12: U1.E15 (IO_L18N_T2_A23_15); also elsewhere on the board
D13: U1.E16 (IO_L17P_T2_A26_15); also elsewhere on the board
EWP: U1.H1 (IO_L20N_T3_35); also elsewhere on the board
G022: U1.L4 (IO_L1P_T0_34); also elsewhere on the board
G023: U1.N3 (IO_L3P_T0_DQS_34); also elsewhere on the board
G026: U1.P1 (IO_L4N_T0_34); also elsewhere on the board
G027: U1.M2 (IO_L2P_T0_34); also elsewhere on the board
G112: U1.R2 (IO_L7P_T1_34); also elsewhere on the board
G113: U1.R1 (IO_L7N_T1_34); also elsewhere on the board
G114: U1.N1 (IO_L4P_T0_34); also elsewhere on the board
G115: U1.N2 (IO_L3N_T0_DQS_34); also elsewhere on the board
G129: U1.L5 (IO_0_34); also elsewhere on the board
G201: U1.M1 (IO_L2N_T0_34); also elsewhere on the board
GCLK: U1.D4 (IO_L12P_T1_MRCC_35); also elsewhere on the board
GMAG: U1.B2 (IO_L8P_T1_AD14P_35); also elsewhere on the board
GSGN: U1.B1 (IO_L9N_T1_DQS_AD7N_35); also elsewhere on the board
OVFL: U1.F15 (IO_L18P_T2_A24_15); also elsewhere on the board
SCLK: U1.D13 (IO_L12P_T1_MRCC_15); also elsewhere on the board

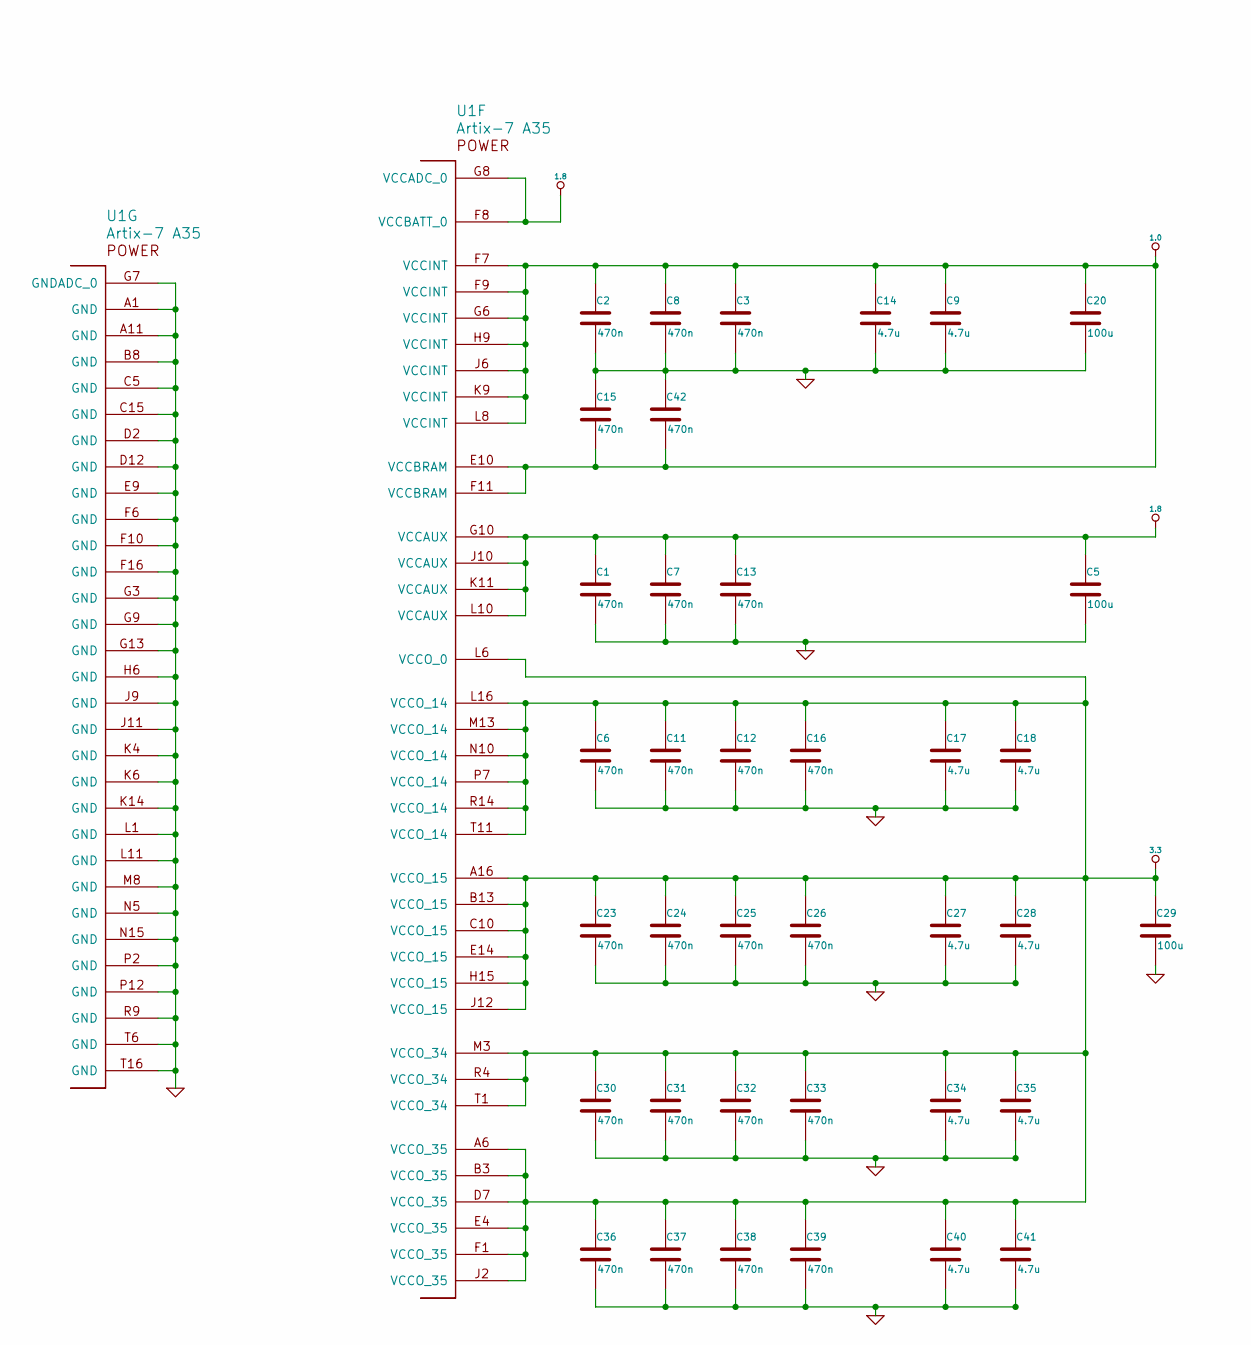
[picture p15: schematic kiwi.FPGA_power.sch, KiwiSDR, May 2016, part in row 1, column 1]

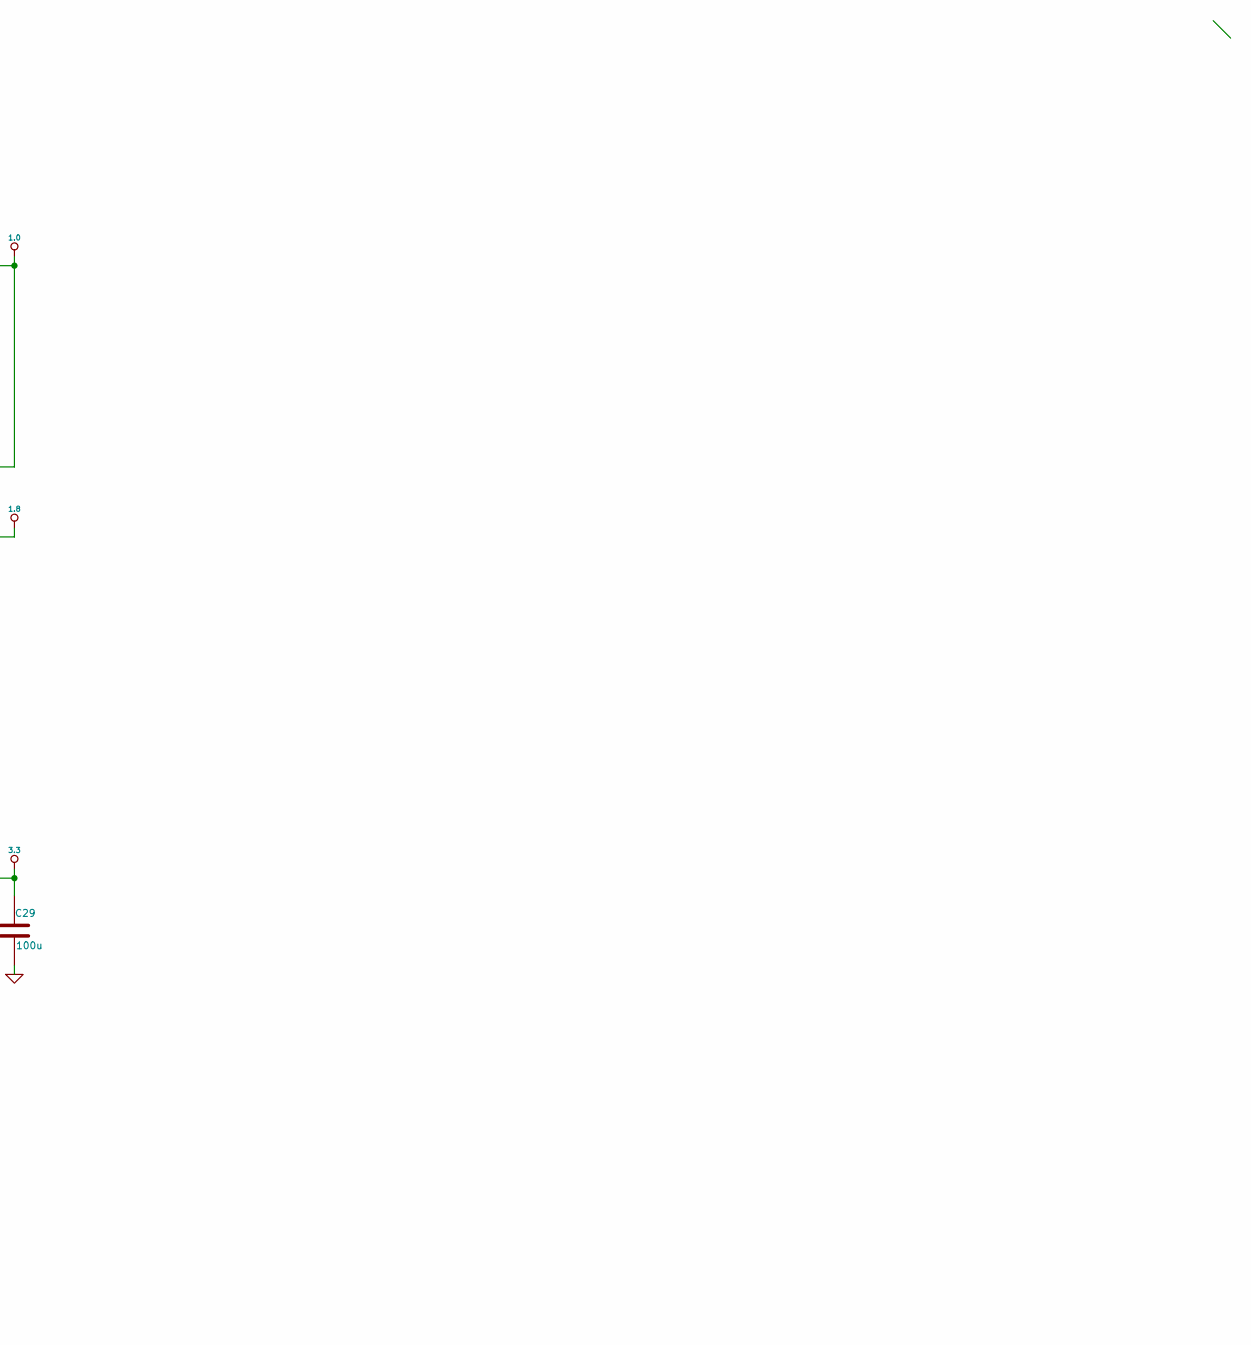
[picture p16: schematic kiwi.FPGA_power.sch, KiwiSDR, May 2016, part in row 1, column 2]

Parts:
C1, C2, C3, C6, C7, C8, C11, C12, C13, C15, C16, C23, C24, C25, C26, C30, C31, C32, C33, C36, C37, C38, C39, C42: 470n; kiwi-SM0402
C5, C20, C29: 100u; kiwi-SM1206
C9, C14, C17, C18, C27, C28, C34, C35, C40, C41: 4.7u; kiwi-SM0402
U1: Artix-7 A35; kiwi-FTG256

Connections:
1.0: C2.1, C3.1, C8.1, C9.1, C14.1, C15.2, C20.1, C42.2, U1.E10 (VCCBRAM), U1.F7 (VCCINT), U1.F9 (VCCINT), U1.F11 (VCCBRAM), U1.G6 (VCCINT), U1.H9 (VCCINT), U1.J6 (VCCINT), U1.K9 (VCCINT), U1.L8 (VCCINT); also elsewhere on the board
1.8: C1.1, C5.1, C7.1, C13.1, U1.F8 (VCCBATT_0), U1.G8 (VCCADC_0), U1.G10 (VCCAUX), U1.J10 (VCCAUX), U1.K11 (VCCAUX), U1.L10 (VCCAUX); also elsewhere on the board

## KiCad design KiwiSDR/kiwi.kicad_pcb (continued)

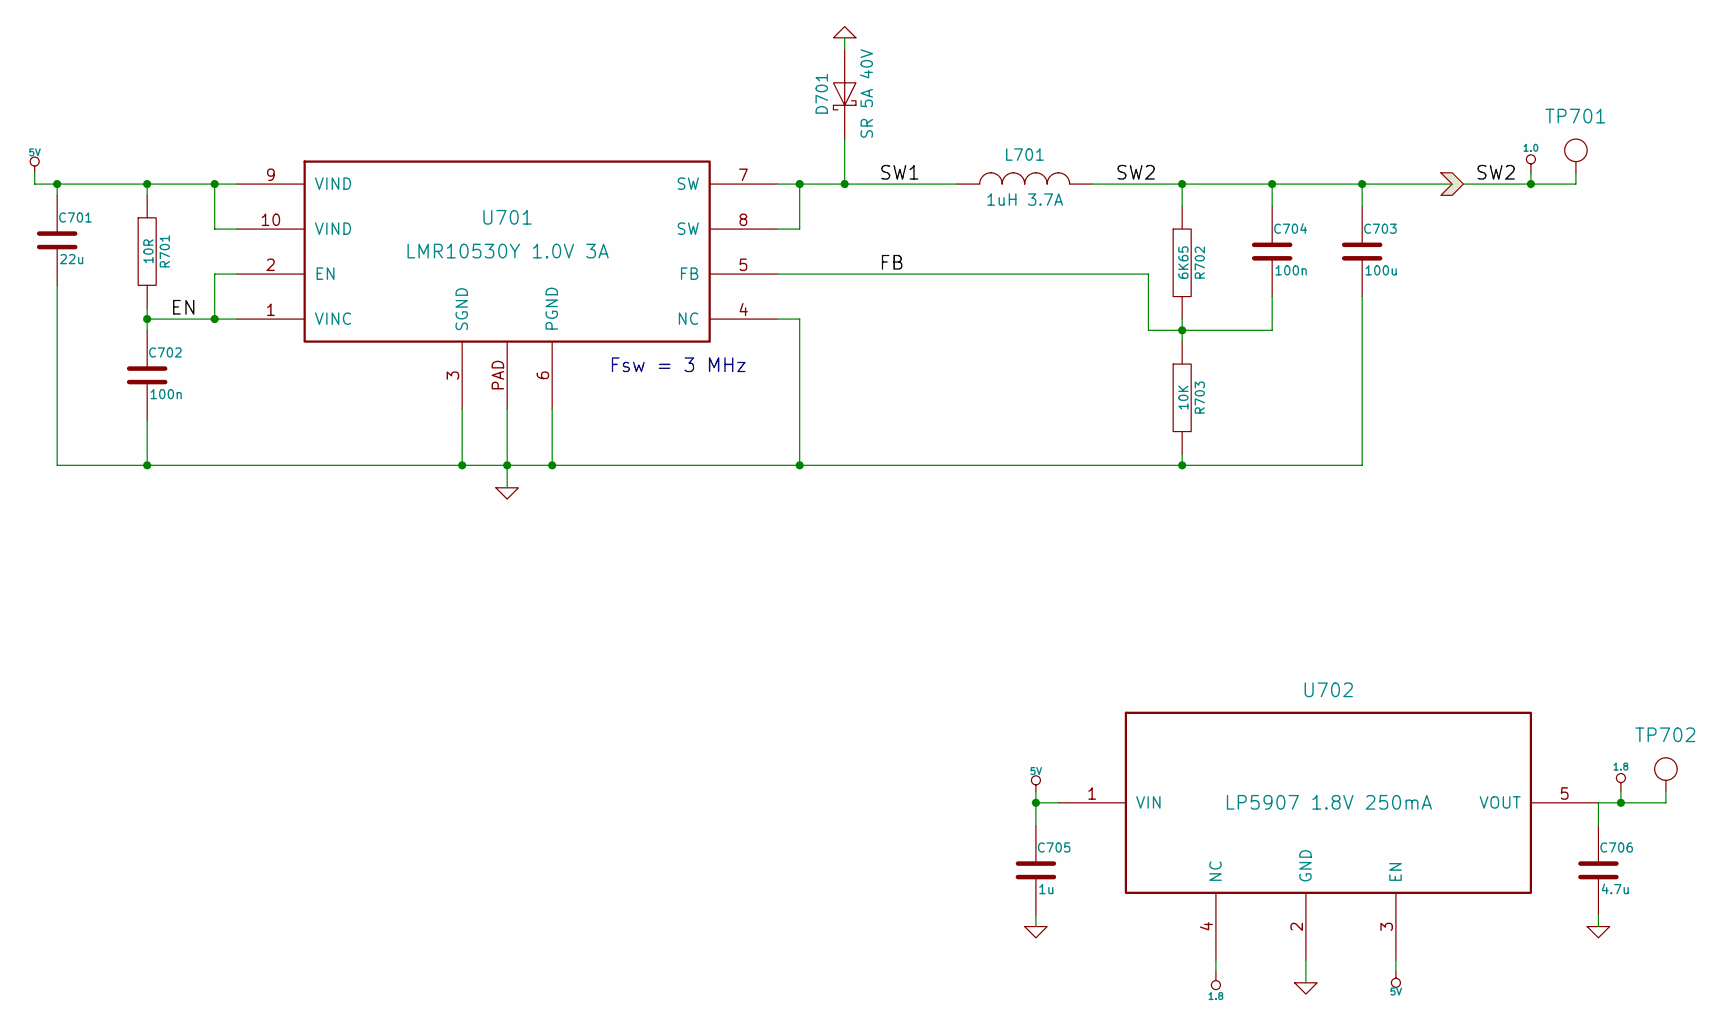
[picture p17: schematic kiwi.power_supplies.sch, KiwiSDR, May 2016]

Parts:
C701: 22u; kiwi-SM0805
C702, C704: 100n; kiwi-SM0402
C703: 100u; kiwi-SM1206
C705: 1u; kiwi-SM0402
C706: 4.7u; kiwi-SM0402
D701: SR 5A 40V; kiwi-DO214_AA
L701: 1uH 3.7A; kiwi-INDUCTOR_4x4
R701: 10R; kiwi-SM0402
R702: 6K65; kiwi-SM0402
R703: 10K; kiwi-SM0402
TP701, TP702: TEST_POINT; kiwi-TP_600
U701: LMR10530Y 1.0V 3A; kiwi-WSON10
U702: LP5907 1.8V 250mA; kiwi-SOT23_5

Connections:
1.0: C703.1, C704.1, L701.2, R702.1, TP701.1; also elsewhere on the board
1.8: C706.1, TP702.1, U702.4 (NC), U702.5 (VOUT); also elsewhere on the board
/Power_Supplies/EN: C702.1, R701.2, U701.1 (VINC), U701.2 (EN)
/Power_Supplies/FB: C704.2, R702.2, R703.1, U701.5 (FB)
/Power_Supplies/SW1: D701.1 (K), L701.1, U701.7 (SW), U701.8 (SW)

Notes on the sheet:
Fsw = 3 MHz

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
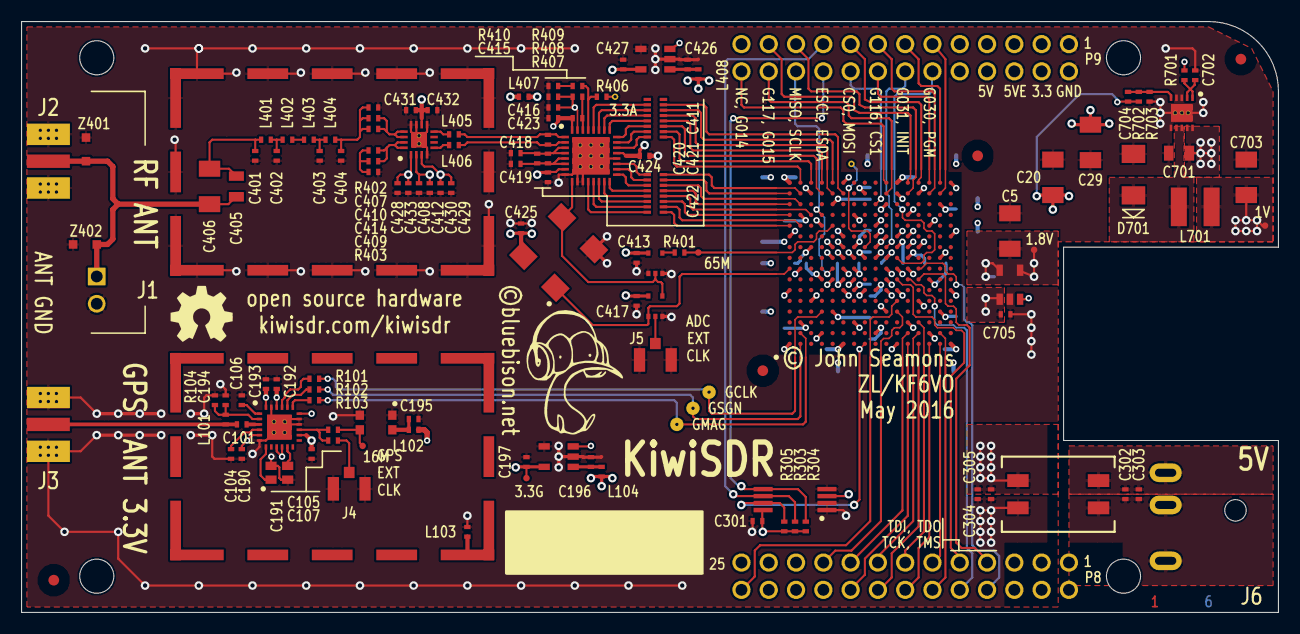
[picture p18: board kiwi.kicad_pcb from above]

Board: 6 copper layers, 117.0 x 55.0 mm, 174 parts (0 on the bottom side), 119 nets.

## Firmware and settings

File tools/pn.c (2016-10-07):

/*
--------------------------------------------------------------------------------
This library is free software; you can redistribute it and/or
modify it under the terms of the GNU Library General Public
License as published by the Free Software Foundation; either
version 2 of the License, or (at your option) any later version.
This library is distributed in the hope that it will be useful,
but WITHOUT ANY WARRANTY; without even the implied warranty of
MERCHANTABILITY or FITNESS FOR A PARTICULAR PURPOSE.  See the GNU
Library General Public License for more details.
You should have received a copy of the GNU Library General Public
License along with this library; if not, write to the
Free Software Foundation, Inc., 51 Franklin St, Fifth Floor,
Boston, MA  02110-1301, USA.
--------------------------------------------------------------------------------
*/

// Copyright (c) 2015-2016 John Seamons, ZL/KF6VO

//
// Add parts number and manufacturer fields to BOM based on value/footprint association.
// Resulting file can be uploaded to e.g. octopart.com for quotation.
//

// octopart.com BOM column assignment order: 5, 2, 7, skip, 3

#include "types.h"

#include <stdio.h>
#include <errno.h>
#include <ctype.h>
#include <string.h>
#include <stdlib.h>
#include <fcntl.h>

void exit(int status);

void sys_panic(char *str)
{
	printf("panic\n");
	perror(str);
	exit(-1);
}

void panic(char *str)
{
	printf("%s\n", str);
	exit(-1);
}

#define	assert(cond) _assert(cond, # cond, __FILE__, __LINE__);

void _assert(int cond, const char *str, const char *file, int line)
{
	if(!(cond)) {
		printf("assert \"%s\" failed at %s:%d\n", str, file, line); exit(-1);
	}
}

char *strdupcat(char *s1, int sl1, char *s2, int sl2)
{
	if (!s1) return s2;
	if (!s2) return s1;
	char *s = (char *) malloc(sl1+sl2+1);
	strncpy(s, s1, sl1);
	strncat(s, s2, sl2);
	return s;
}

// PROJECT is passed from Makefile
#define	PFILE(basename)		STRINGIFY_DEFINE(PROJECT) basename

#define	KICAD_CSV_FILE	PFILE(".csv")
#define	TO_OCTO_FILE	PFILE(".bom.csv")
#define	TO_DNL_FILE		PFILE(".bom.dnl.csv")
#define	TO_ODS_FILE		PFILE(".bom.ods.csv")
#define	INSERT_FILE		PFILE(".insert.txt")

#define	FROM_OCTO_FILE	PFILE(".bom.octo.csv")
#define	DIGIKEY_FILE	PFILE(".bom.digi.csv")
#define	MOUSER_FILE		PFILE(".bom.mou.csv")
#define	NEWARK_FILE		PFILE(".bom.new.csv")
#define	AVNET_EXP_FILE	PFILE(".bom.avex.csv")

#define NBUF 1024
char linebuf[NBUF];

#define	BAD			-1
#define	SHT_FPWR	0
#define	SHT_GPS		1
#define	SHT_INJ		2
#define	SHT_BONE	3
#define	SHT_ADC		4
#define	SHT_ANT		5
#define	SHT_FIO		6
#define	SHT_SWREG	7
#define NSHEETS		8
char *sheet_name[NSHEETS+1] = { "Fpwr", "gps", "inj", "bone", "adc", "ant", "Fio", "swreg", "TOTAL" };
int sheet_count[NSHEETS+1];
float sheet_price[NSHEETS+1];


// stats needed by assembly/PCB companies
#define	SMT		0
#define	NLP		1
#define	TH		2
#define	EDGE	3
#define	MAN		4
#define	NP		5
#define	VIR		6
#define	DNL		7
#define	NPLACE	8

char *place[] = { "SMT", "no_lead", "T/H", "edge", "manual", "no_proto", "virtual", "DNL" };
int ccount[NPLACE];

// attributes
#define	NA		0
#define	FP		0x01		// fine-pitch, <= 0.5mm pin centers
#define	GP		0x02		// generic part
#define	HC		0x04		// high-cost part
#define	POL		0x08		// polarized
#define	OPL		0x10		// OPL: Open Parts Library
#define	SQ		0x20		// special quotation
#define	NATTR	6

#define X		0, NA
#define G		0, GP

char *attr_str[] = { "fine_pitch", "generic", "high_cost", "polarized", "OPL", "special quote" };
int acount[NATTR];

typedef struct {
	int place;
	char *val, *pkg, *mfg, *pn;
	int pads, attr;
	char *specs, *notes, *crit, *mark;
	int force_quan;
	char *custom_pn;
	
	char *refs;
	int quan, sheet[NSHEETS];
	float price;
	char *dist, *sku;
	int seen;
} pn_t;

int npads;

//	sheet	refs	connectors
//	ADC		4xx		rf=J1/2 extclk=J5
//	GPS		1xx		in=J3 extclk=J4
//	Bone	3xx		ZB1
//	a.ant	5xx		rf=J10/11/13 pwr=J12
//	fpga_p	01x
//	pwr		7xx
//	inj		2xx		ant=J20/21/22/23 rx1=J24/25 rx2=J26/27 gnd=J28 AC=J29

int connectors[] = {
	// J0-9
	BAD, SHT_ADC, SHT_ADC, SHT_GPS, SHT_GPS, SHT_ADC, BAD, BAD, BAD, BAD,
	
	// J10-19
	SHT_ANT, SHT_ANT, SHT_ANT, SHT_ANT, BAD, BAD, BAD, BAD, BAD, BAD,
	
	// J20-29
	SHT_INJ, SHT_INJ, SHT_INJ, SHT_INJ, SHT_INJ, SHT_INJ, SHT_INJ, SHT_INJ, SHT_INJ, SHT_INJ,
};

// fixme
//	v.reg fb resis optim?
//	fill-out generic parts
//	fill-out critical specs

#define RES_THICK_FILM	"thick film resistor"
#define S_1P_100m_50V	"1% 100mW 50V", RES_THICK_FILM
#define S_1P_125m_150V	"1% 125mW 150V", RES_THICK_FILM
#define S_1P_500m_150V	"1% 500mW 150V", RES_THICK_FILM
#define S_1P_660m_500V	"1% 660mW 500V", RES_THICK_FILM

#define CAP_CERAMIC		"ceramic capacitor"
#define S_5P_C0G_50V	"5% C0G 50V", CAP_CERAMIC
#define S_5P_C0G_100V	"5% C0G 100V", CAP_CERAMIC
#define S_20P_X7R_100V	"20% X7R 100V", CAP_CERAMIC
#define S_10P_X7R_100V	"10% X7R 100V", CAP_CERAMIC
#define S_10P_X7R_50V	"10% X7R 50V", CAP_CERAMIC
#define S_10P_X7R_16V	"10% X7R 16V", CAP_CERAMIC
#define S_10P_X5R_35V	"10% X5R 35V", CAP_CERAMIC
#define S_10P_X5R_25V	"10% X5R 25V", CAP_CERAMIC
#define S_20P_X5R_6V3	"20% X5R 6.3V", CAP_CERAMIC

pn_t pn[] = {
// resistors
{SMT, "0R",						"kiwi-SM0402",		"Panasonic",		"ERJ-2GE0R00X", G, "", "zero-ohm jumper" },
{SMT, "10R",					"kiwi-SM0402",		"Panasonic",		"ERJ-2RKF10R0X", G, S_1P_100m_50V },
{SMT, "28R7",					"kiwi-SM0402",		"Panasonic",		"ERJ-2RKF28R7X", G, S_1P_100m_50V },
{SMT, "66R5",					"kiwi-SM0402",		"Panasonic",		"ERJ-2RKF66R5X", G, S_1P_100m_50V },
{SMT, "100R",					"kiwi-SM0402",		"Panasonic",		"ERJ-2RKF1000X", G, S_1P_100m_50V },
{SMT, "1K5",					"kiwi-SM0402",		"Panasonic",		"ERJ-2RKF1501X", G, S_1P_100m_50V },
{SMT, "5K6",					"kiwi-SM0402",		"Panasonic",		"ERJ-2RKF5601X", G, S_1P_100m_50V },
{SMT, "6K65",					"kiwi-SM0402",		"Panasonic",		"ERJ-2RKF6651X", G, S_1P_100m_50V },
{SMT, "10K",					"kiwi-SM0402",		"Panasonic",		"ERJ-2RKF1002X", G, S_1P_100m_50V },

{SMT, "0R",						"kiwi-SM0805",		"Panasonic",		"ERJ-6GEY0R00V", G, "", "zero-ohm jumper" },
{SMT, "10R/0.5W",				"kiwi-SM0805",		"Panasonic",		"ERJ-P06F10R0V", G, S_1P_500m_150V },
{SMT, "47R",					"kiwi-SM0805",		"Panasonic",		"ERJ-6ENF47R0V", G, S_1P_125m_150V },
{SMT, "100R",					"kiwi-SM0805",		"Panasonic",		"ERJ-6ENF1000V", G, S_1P_125m_150V },
{SMT, "220R/0.5W",				"kiwi-SM0805",		"Panasonic",		"ERJ-P06F2200V", G, S_1P_500m_150V },
{SMT, "470R",					"kiwi-SM0805",		"Panasonic",		"ERJ-6ENF4700V", G, S_1P_125m_150V },
{SMT, "680R",					"kiwi-SM0805",		"Panasonic",		"ERJ-6ENF6800V", G, S_1P_125m_150V },
{SMT, "1K",						"kiwi-SM0805",		"Panasonic",		"ERJ-6ENF1001V", G, S_1P_125m_150V },
{SMT, "1K5",					"kiwi-SM0805",		"Panasonic",		"ERJ-6ENF1501V", G, S_1P_125m_150V },
{SMT, "2K2",					"kiwi-SM0805",		"Panasonic",		"ERJ-6ENF2201V", G, S_1P_125m_150V },
{SMT, "10K",					"kiwi-SM0805",		"Panasonic",		"ERJ-6ENF1002V", G, S_1P_125m_150V },
{SMT, "11K",					"kiwi-SM0805",		"Panasonic",		"ERJ-6ENF1102V", G, S_1P_125m_150V },
{SMT, "11K5",					"kiwi-SM0805",		"Panasonic",		"ERJ-6ENF1152V", G, S_1P_125m_150V },
{SMT, "100K",					"kiwi-SM0805",		"Panasonic",		"ERJ-6ENF1003V", G, S_1P_125m_150V },
{SMT, "1M",						"kiwi-SM0805",		"Panasonic",		"ERJ-6ENF1004V", G, S_1P_125m_150V },

{SMT, "10R/0.66W",				"kiwi-SM1206",		"Panasonic",		"ERJ-P08F10R0V", G, S_1P_660m_500V },
{SMT, "220R/0.66W",				"kiwi-SM1206",		"Panasonic",		"ERJ-P08F2200V", G, S_1P_660m_500V },

{SMT, "100R",					"kiwi-RNET_CAY16_J8", "Bourns",	"CAY16-101J8LF", 16, GP|FP, "5% 62.5mW 25V", "isolated resistor array" },

// caps
{SMT, "22p",					"kiwi-SM0402",		"Murata",	"GRM1555C1H220JA01D", G, S_5P_C0G_50V },
{SMT, "56p/100",				"kiwi-SM0402",		"Murata",	"GRM1555C2A560JA01D", G, S_5P_C0G_100V, ">= 100V" },
{SMT, "100p",					"kiwi-SM0402",		"Murata",	"GRM1555C1H101JA01D", G, S_5P_C0G_50V },
{SMT, "160p/50",				"kiwi-SM0402",		"Murata",	"GRM1555C1H161JA01D", G, S_5P_C0G_50V, ">= 50V" },
{SMT, "1n",						"kiwi-SM0402",		"Murata",	"GCM155R71H102KA37D", G, S_10P_X7R_50V },
{SMT, "10n",					"kiwi-SM0402",		"Murata",	"GRM155R71C103KA01D", G, S_10P_X7R_16V },
{SMT, "100n",					"kiwi-SM0402",		"Murata",	"GRM155R71C104KA88D", G, S_10P_X7R_16V },
{SMT, "470n",					"kiwi-SM0402",		"Murata",	"GRM155R6YA474KE01D", G, S_10P_X5R_35V },
{SMT, "1u",						"kiwi-SM0402",		"Murata",	"GRM155R61E105KA12D", G, S_10P_X5R_25V },
{SMT, "2.2u",					"kiwi-SM0402",		"Murata",	"GRM155R60J225ME15D", G, S_20P_X5R_6V3 },
{SMT, "4.7u",					"kiwi-SM0402",		"Murata",	"GRM155R60J475ME47D", G, S_20P_X5R_6V3 },

{SMT, "1n/100",					"kiwi-SM0805",		"Murata",	"GRM219R72A102KA01J", G, S_10P_X7R_100V, ">= 100V" },
{SMT, "100n/100",				"kiwi-SM0805",		"Murata",	"GRM21BR72A103KA01L", G, S_10P_X7R_100V },
{SMT, "10u/25",					"kiwi-SM0805",		"Murata",	"GRM219R61E106KA12D", G, S_10P_X5R_25V },
{SMT, "22u",					"kiwi-SM0805",		"Murata",	"GRM21BR60J226ME39L", G, S_20P_X5R_6V3, },

{SMT, "470n/100",				"kiwi-SM1206",		"AVX",		"ESD61C474K4T2A-28", G, S_10P_X7R_100V, ">= 100V" },
{SMT, "100u",					"kiwi-SM1206",		"Murata",	"GRM31CR60J107ME39L", G, S_20P_X5R_6V3 },

{SMT, "22u/25 TA",				"kiwi-CAP_D",		"Kemet",	"T491D226K025AT", G, "10% 25V 0R8ESR", "tantalum capacitor" },
{SMT, "330u/35 EL",				"kiwi-CAP_10x10",	"Nichicon",	"UWT1V331MNL1GS", G, "20% 35V 0A3RIPPLE", "aluminum electrolytic capacitor" },

// inductors
{SMT, "FB 80Z",					"kiwi-SM0805",		"TDK",		"MMZ2012D800B", G, "25% 500mA 80Z@100M", "ferrite chip" },
{SMT, "FB 600Z",				"kiwi-SM0402",		"TDK",		"MMZ1005B601C", G, "25% 200mA 600Z@100M", "ferrite chip" },
{SMT, "39nH",					"kiwi-SM0402",		"TDK",		"MLK1005S39NJ", X, "5% 200mA 2GHzSelfRes 6Q@100M", "chip inductor", ">= 2GHz self-resonance (above GPS L1)" },
{SMT, "150nH",					"kiwi-SM0402",		"TDK",		"MLG1005SR15J", G, "5% 150mA 8Q@100M", "chip inductor" },
{SMT, "270nH",					"kiwi-SM0402",		"TDK",		"MLG1005SR27J", G, "3% 100mA 8Q@100M", "chip inductor" },
{SMT, "330nH",					"kiwi-SM0402",		"TDK",		"MLG1005SR33J", G, "3% 50mA 6Q@100M", "chip inductor" },

{SMT, "1uH 3.7A",				"kiwi-INDUCTOR_4x4", "Bourns",	"SRN4018-1R0Y", G, "ferrite 30% 3.7A", "inductor; use: SMPS" },
{SMT, "100uH",					"kiwi-SM1812",		"TDK",		"B82432T1104K", X, "ferrite 10% 200mA 20Q@0.8MHz", "inductor; use: bias tee", ">= 200 mA DC" },
{SMT, "CMC 500uH 1A",			"kiwi-CMC",			"Bourns",	"SRF0905A-501Y", 4, NA, "ferrite 50% 1A", "inductor; use: bias tee", "<= 0.15R", "501Y" },
{SMT, "CMC 2mH 0.6A",			"kiwi-CMC",			"Bourns",	"SRF0905A-202Y", 4, NA, "ferrite 50% 600mA", "inductor; use: bias tee", "<= 0.42R", "202Y" },
{SMT, "20mH 1A",				"kiwi-CMC_22x22",	"Bourns",	"PM3700-80-RC", G, "ferrite 1A 0.25R", "inductor; use: bias tee", ">= 200 mA DC" },
{NLP, "SAW L1",					"kiwi-SAW",			"RFM",		"SF1186G", 4, GP, "1572.42MHz 2MHzBW", "GPS SAW filter", "", "2A" },

{SMT, "T1-6",					"kiwi-MCL_KK81",	"MCL",		"T1-6-KK81+", 6, NA, "1:1 10kHZ-150MHz ", "RF transformer" },
{SMT, "T-622",					"kiwi-MCL_KK81",	"MCL",		"T-622-KK81+", 6, NA, "1:1:1 100KHz-200MHz", "RF transformer" },

// semis
{NLP, "SE4150L",				"kiwi-QFN24",		"Skyworks",	"SE4150L-R", 24, FP, "", "GPS front-end" },
{SMT, "EEPROM 32Kx8",			"kiwi-TSSOP8",		"On Semi",	"CAT24C256YI-GT3", 8, GP, "256kb=32kx8b 100k/400k/1MHz I2C", "EEPROM" },
{SMT, "NC7SZ125",				"kiwi-SC70_5",		"Fairchild", "NC7SZ125P5X", 5, NA, "3.3V 2.6nsTpd", "clock buffer", "", "Z25" },

{NLP, "LMR10530Y 1.0V 3A",		"kiwi-WSON10",		"TI",		"LMR10530YSD/NOPB", 10, FP, "5.5Vin 3A 3MHz", "step-down voltage reg" },
{SMT, "LP5907 3.3V 250mA",		"kiwi-SOT23_5",		"TI",		"LP5907QMFX-3.3Q1", 5, NA, "3.3V 250mA 0.12Vdo", "low-noise LDO voltage reg" },
{SMT, "LP5907 1.8V 250mA",		"kiwi-SOT23_5",		"TI",		"LP5907QMFX-1.8Q1", 5, NA, "1.8V 250mA 0.12Vdo", "low-noise LDO voltage reg" },
{SMT, "LM2941",					"kiwi-TO263",		"TI",		"LM2941SX/NOPB", 6, NA, "26Vin 1.0A 1.0Vdo", "adj LDO voltage reg" },
{SMT, "TPS7A4501",				"kiwi-SOT223_6",	"TI",		"TPS7A4501DCQR", 6, NA, "20Vin 1.5A 0.3Vdo", "adj low-noise LDO voltage reg" },

{SMT, "J310",					"kiwi-SOT23_DGS",	"Fairchild", "MMBFJ310", 3, GP, "25Vds", "N-chan JFET", "", "6T", 0, "512-MMBFJ310" },
{SMT, "J271",					"kiwi-SOT23_DGS",	"Fairchild", "MMBFJ271", 3, GP, "30Vgs", "P-chan JFET", "", "62T", 0, "512-MMBFJ271" },
{SMT, "BFG35",					"kiwi-SOT223_EBEC",	"NXP",		"BFG35.115", 3, NA, "18Vceo 4GHz", "NPN wideband", "", 0, 0, "771-BFG35-T/R" },
{SMT, "BFG31",					"kiwi-SOT223_EBEC",	"NXP",		"BFG31.115", 3, NA, "15Vceo 5GHz", "PNP wideband", "", 0, 0, "771-BFG31-T/R" },
{SMT, "MMBT4401",				"kiwi-SOT23_BCE",	"On Semi",	"MMBT4401LT1G", 3, GP, "40Vceo 600mAIc", "NPN switching BJT", "", "2X", 0, "863-MMBT4401LT1G" },

{SMT, "SR 5A 40V",				"kiwi-DO214_AA",	"Vishay",	"SSB44-E3/52T", 0, POL, "40V 0.42Vf 4.0AIf ", "Schottky rectifier; use: SMPS", "<= 0.42 Vf", "S44" },
{SMT, "BR 0.5A 400V",			"kiwi-TO269_AA",	"Vishay",	"MB2S-E3/80", 4, GP, "200V 0.5AIf", "bridge rectifier", "", "2" },
{SMT, "TVS 3.3V",				"kiwi-SOD323",		"Bourns",	"CDSOD323-T03C", G, "3.3Vw 4.0Vbr 7.0Vclamp 3pF", "bi-directional TVS", "", "3C" },
{SMT, "TVS 25VAC",				"kiwi-SM0805",		"AVX",		"VC080531C650DP", G, "25VACwv 65Vclamp 0.3J", "TVS protection" },
{SMT, "PPTC 200 mA",			"kiwi-SM1812",		"Bourns",	"MF-MSMF020/60-2", G, "60Vmax 0.2Ahold 0.4Atrip 0.15SecTrip", "PTC resettable fuse" },
{SMT, "75V",					"kiwi-GDT",			"TE Conn",	"GTCS23-750M-R01-2", G, "75V 20% <0.5pF", "gas discharge tube" },

{NLP, "65.360 MHz",				"kiwi-VCXO",		"CTS",		"357LB3I065M3600", 4, GP, "3.3V 50ppm 1psTjms", "VCXO: prototype with 65.36 MHz since distributors stock this freq; for production special order 65.000 MHz from manufacturer", "<= 1ps RMS phase jitter" },
{NLP, "66.6666 MHz",			"kiwi-XO",			"Conner Winfield", "CWX823-066.6666M", 4, GP, "3.3V 50ppm 1psTjms", "XO: prototype with 66.6666 MHz since distributors stock this freq; for production special order 65.000 MHz from manufacturer", "<= 1ps RMS phase jitter" },
{NLP, "16.368 MHz",				"kiwi-TCXO",		"TXC",		"7Q-16.368MBG-T", 4, GP, "3.3V clipped sinewave tempco 0.5ppm", "TCXO", "tempco 0.5 ppm" },

// connectors
{SMT, "POWER JACK 2.1MM",		"kiwi-JACK_2_1MM_SMD", "Switchcraft", "RASM722PX", G, "2.1mm w/ locating pin", "power jack" },

// mechanical
{SMT, "RF_SHIELD 29x19",		"*",				"Laird",	"BMI-S-209-F", 12, GP, "29x19mm; 7mm high", "RF shield frame" },
{MAN, "RF_SHIELD_COVER 29x19",	"kiwi-RF_SHIELD_COVER", "Laird", "BMI-S-209-C", G, "29x19mm", "RF shield cover; manual install" },

// special quote
{NLP, "Artix-7 A35",			"kiwi-FTG256",		"Xilinx",	"XC7A35T-1FTG256C", 256, HC|SQ, "17x17 1.0mm BGA", "FPGA" },
{NLP, "LTC2248",				"kiwi-QFN32",		"Linear Tech", "LTC2248CUH#PBF", 32, FP|HC|SQ, "14-bit 65MHz 240mW", "ADC" },
{NLP, "LTC6401-20",				"kiwi-QFN16",		"Linear Tech", "LTC6401CUD-20#PBF", 16, FP|SQ, "+20dB 6.2dBNF 1.3GHz", "differential ADC driver" },
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
int main(int argc, char *argv[])
{
	int i, j;
	FILE *fpr, *fow, *f2w, *fpw, *fiw, *fmw, *fdw[5];

	char *lb;
	char *s, *t;
	pn_t *p;
	
	if (argc >= 2) goto bom_octo;

	printf("creating BOM files \"%s\", \"%s\", \"%s\" and \"%s\" by assigning part/mfg info,\nbased on KiCAD-generated \"%s\" BOM file\n",
		TO_OCTO_FILE, TO_DNL_FILE, TO_ODS_FILE, INSERT_FILE, KICAD_CSV_FILE);
	if ((fpr = fopen(KICAD_CSV_FILE, "r")) == NULL) sys_panic("fopen " KICAD_CSV_FILE);
	if ((fow = fopen(TO_OCTO_FILE, "w")) == NULL) sys_panic("fopen " TO_OCTO_FILE);
	if ((f2w = fopen(TO_DNL_FILE, "w")) == NULL) sys_panic("fopen " TO_DNL_FILE);
	if ((fpw = fopen(TO_ODS_FILE, "w")) == NULL) sys_panic("fopen " TO_ODS_FILE);
	if ((fiw = fopen(INSERT_FILE, "w")) == NULL) sys_panic("fopen " INSERT_FILE);
	if ((fmw = fopen(MOUSER_FILE, "w")) == NULL) sys_panic("fopen " MOUSER_FILE);
	
	fprintf(fpw, "item#, quan, value, mfg, P/N, package, place, refs, SMD marking, fine pitch, polarized, generic substitution, OPL, specs, critical spec, notes\n");
	fprintf(fmw, "item#, quan, DNL, value, mfg, P/N, package, refs, mouser p/n\n");
	
	while (fgets(linebuf, NBUF, fpr)) {
		s = lb = strdup(linebuf);
		int dnl = 0;
		char *val = strsep(&s, ",");
		char *quan_s = strsep(&s, ",");
		char *refs = strsep(&s, ",");
		char *pkg = strsep(&s, ",");

		if (!strncmp(val, "DNL", 3)) {
			val += 3;
			if (*val == ' ') val++; else val = "(DNL)";
			dnl = 1;
		}

		// remove quotes around refs
		if (*refs == '"') refs++;
		t = refs + strlen(refs)-1;
		if (*t == '"') *t = 0;

		t = pkg + strlen(pkg)-1;
		if (*t == '\n') *t = 0;
		if (*pkg == 0) pkg = "(*fix pkg)";

		int quan = strtol(quan_s, NULL, 0);
		
		// accumulate BOM quantities into table due to wildcard matching
		for (p = pn; p->val; p++) {
			//printf("<%s> <%s>   <%s> <%s>\n", val, p->val, pkg, p->pkg);
			if ((!strcmp(p->val, "*") || !strcmp(p->val, val)) && (!strcmp(p->pkg, "*") || !strcmp(p->pkg, pkg))) {
				if (dnl) {
					ccount[DNL] += quan;
					//p->refs = refs;
					//p->quan = quan;
					fprintf(f2w, "DNL %s, %d, %s, %s, %s, %s\n", val, quan, p->mfg, p->pn, pkg, refs);
					proto_items++;
					fprintf(fpw, "#%d, %d, %s, %s, %s, %s, DNL, %s, %s, %s, %s, %s, %s%s, %s, %s, DO NOT LOAD; %s\n", proto_items, quan, val, p->mfg, p->pn, _pkg(pkg), refs,
						p->mark? p->mark:"", (p->attr & FP)? "FINE":"", (p->attr & POL)? "YES":"", (p->attr & GP)? "YES":"-- NO --",
						(p->attr & OPL)? "OPL ":"", (p->attr & OPL)? p->custom_pn:"",
						p->specs? p->specs:"", p->crit? p->crit:"", p->notes? p->notes:"");
					fprintf(fmw, "#%d, %d, DNL, %s, %s, %s, %s, %s, %s\n", proto_items, quan, val, p->mfg, p->pn, _pkg(p->pkg), refs, p->custom_pn? p->custom_pn :"");
				} else
				if (p->place == VIR) {
					ccount[VIR] += quan;
					fprintf(f2w, "VIR %s, %d, , , %s, %s\n", val, quan, pkg, refs);
				} else
				if (!dnl) {
					quan = p->force_quan? p->force_quan : quan;
					p->quan += quan;		// += due to wildcard matching
					ccount[p->place] += quan;
					ccount_tot += quan;
					
					for (i=0,j=1; i<NATTR; i++,j<<=1) {
						if (p->attr & j) acount[i] += quan;
					}
					
					if (p->place == NLP) {
						if (!p->pads) { printf("%s needs #pads specified\n", p->val); panic("npads"); }
						npads += quan * p->pads;
						//printf("%3d q%2d p%3d NLP %s\n", npads, quan, p->pads, p->val);
					} else
					if (p->place == SMT) {
						int pads = (!p->pads)? 2 : p->pads;
						npads += quan * pads;
						//printf("%3d q%2d p%3d SMT %s\n", npads, quan, pads, p->val);
					}
					
					// merge refs for wildcard case
					if (p->refs) {
						int sl1 = strlen(p->refs), sl2 = strlen(refs);
						p->refs[sl1] = ' ';		// okay to clobber terminating null since strdupcat uses strncpy/strncat
						p->refs = strdupcat(p->refs, sl1+1, refs, sl2);
					} else {
						p->refs = refs;
					}
				}
				break;
			}
		}
		
		// not in list
		if (!p->val) {
			if (!strcmp(val, "(DNL)")) {
				fprintf(f2w, "DNL no value, %d, , , %s, %s\n", quan, pkg, refs);
				ccount[DNL] += quan;
				proto_items++;
				fprintf(fpw, "#%d, %d, (no value), , , %s, DNL, %s, , , , YES, , , , DO NOT LOAD\n", proto_items, quan, _pkg(pkg), refs);
				fprintf(fmw, "#%d, %d, DNL, (no value), , , %s, %s,\n", proto_items, quan, _pkg(pkg), refs);
			} else {
				printf("%s%s, %d, [*no_part], , %s, %s\n", dnl? "DNL ":"", val, quan, pkg, refs);
			}
		}
	}
	
	int local_tot = 0;

	fprintf(fpw, "\n");
	for (p = pn; p->val; p++) {
		if (p->quan) {
			bom_items++; proto_items++;
			if (!(p->attr & OPL)) {
				fprintf(fow, "#%d, %d, %s, %s, %s, %s, %s\n", bom_items, p->quan, p->val, p->mfg, p->pn, p->pkg, p->refs);
				fprintf(fmw, "#%d, %d, , %s, %s, %s, %s, %s, %s\n", proto_items, p->quan, p->val, p->mfg, p->pn, _pkg(p->pkg), p->refs, p->custom_pn? p->custom_pn :"");
			}
			fprintf(fpw, "#%d, %d, %s, %s, %s, %s, %s, %s, %s, %s, %s, %s, %s%s, %s, %s, %s\n", proto_items, p->quan, p->val, p->mfg, p->pn, _pkg(p->pkg), _place(p), p->refs,
				p->mark? p->mark:"", (p->attr & FP)? "FINE":"", (p->attr & POL)? "YES":"", (p->attr & GP)? "YES":"-- NO --",
				(p->attr & OPL)? "OPL ":"", (p->attr & OPL)? p->custom_pn:"",
				p->specs? p->specs:"", p->crit? p->crit:"", p->notes? p->notes:"");
			local_tot += p->quan;
			
			// a file of SMT and NLP refs to compare against centroid file that use modules that have insert attribute set
			char *refs = strdup(p->refs);
			t = refs; while (*t) { if (*t == ' ') *t = '\n'; t++; }		// one ref per line
			if (p->place == SMT || p->place == NLP) fprintf(fiw, "%s\n", refs);
		}
	}

	if (ccount_tot != local_tot) {
		printf("ccount_tot %d, local_tot %d\n", ccount_tot, local_tot);
		assert(ccount_tot == local_tot);
	}
	
	// stats needed by proto assembly/PCB companies
	printf("BOM items: %d total\n", bom_items);
	
	printf("component count: %3d total", ccount_tot);
	for (i=0; i<NPLACE; i++) printf(", %d %s", ccount[i], place[i]);
	printf("\nSMT + no_lead = %d (check against centroid file count)\n", ccount[SMT]+ccount[NLP]);
	
	printf("attributes: ");
	for (i=0,j=1; i<NATTR; i++,j<<=1) printf("%s%d %s", (i>0)? ", ":"", acount[i], attr_str[i]);
	printf("\n");
	
	printf("other: %d SMT pads\n", npads);

	fclose(fpr);
	fclose(fow);
	fclose(f2w);
	fclose(fpw);
	fclose(fiw);
	fclose(fmw);
	exit(0);
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

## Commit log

2016-10-07 long overdue update to v1.0 PCB files
    These are the files used in the current production PCBs.
    [kiwi-B_Mask.gbs, kiwi-B_Paste.gbp, kiwi-B_SilkS.gbo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]
2016-12-09 new silkscreen with more refs
    [kiwi-F_SilkS.gto]

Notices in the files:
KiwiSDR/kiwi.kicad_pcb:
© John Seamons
